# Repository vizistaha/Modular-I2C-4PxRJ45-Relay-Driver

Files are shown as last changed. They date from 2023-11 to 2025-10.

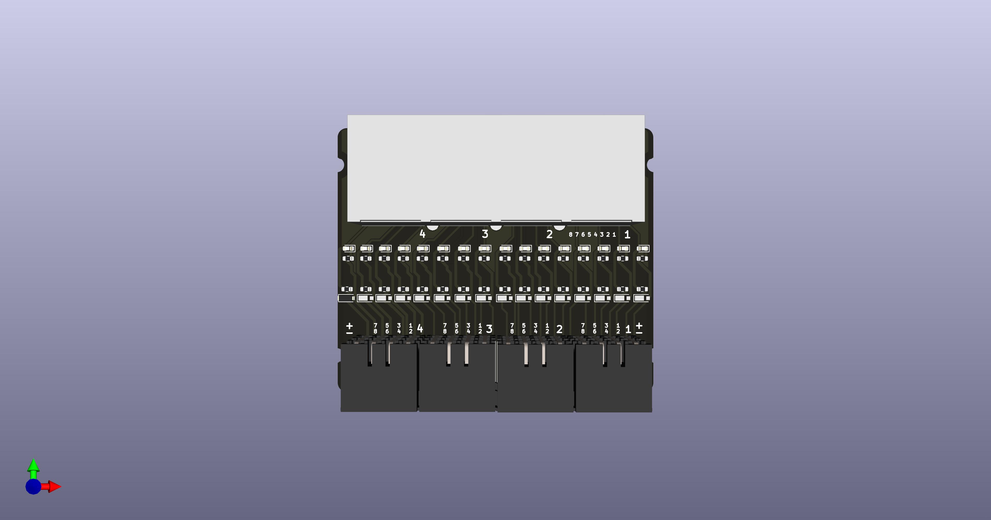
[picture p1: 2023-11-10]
RJ45toTerminal/RJ45-To-Terminal_3D.jpg

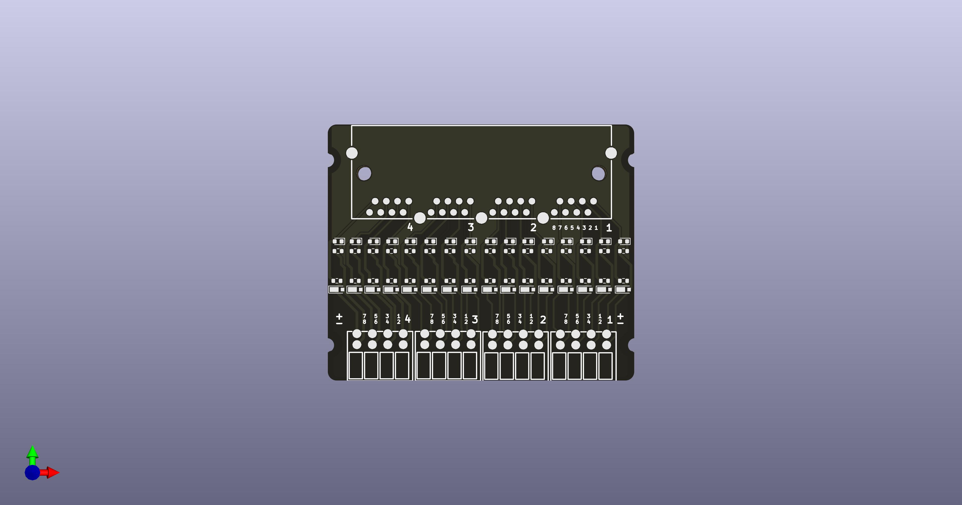
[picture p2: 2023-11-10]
RJ45toTerminal/RJ45-To-Terminal_Board.jpg

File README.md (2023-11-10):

# Modular-I2C-4PxRJ45-Relay-Driver
an oxrs compatible I2C-4PxRJ45-Relay-Driver board in a modular format. Inspired by 8-Channel Relay Driver Shield from Superhouse and Modular-I2CRJ45 from Austin's Creations.

rev 1 - non isolated version  
rev 2 - power circuit is fully isolated from mcu circuit by optocoupler  
rev 2_1 - output uses pluggable terminal instead of 4PxRJ45  
RJ45toTerminal - breakout board for rj45 to pluggable connector (check read me for pin mapping)

For more details about OXRS: https://oxrs.io/

Credits
-------
 * Austin's Creations <https://www.austinscreations.ca/>
 * Jonathan Oxer <https://www.superhouse.tv/>

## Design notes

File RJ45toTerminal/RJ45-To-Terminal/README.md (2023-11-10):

# RJ45 To Terminal Mapping

| Pin | Pair | Color | Terminal  | 
| --- |:---:| --- | --- |
| 1 | 1+ | Orange-White | 1 | 
| 2 | 1- | Orange | 2 |
| 3 | 2+ | Green-White  | 3 |
| 6 | 2- | Green | 4 |
| 5 | 3+ | Blue-White | 5 |
| 4 | 3- | Blue | 6 |
| 7 | 4+ | Brown-White  | 7 |
| 8 | 4- | Brown | 8 |

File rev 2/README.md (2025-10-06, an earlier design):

# RJ45 Pinout

| Pin | Pair | Color |
| --- |:---:| --- |
| 1 | 1+ | Orange-White |
| 2 | 1- | Orange |
| 3 | 2+ | Green-White  |
| 6 | 2- | Green |
| 5 | 3+ | Blue-White |
| 4 | 3- | Blue |
| 7 | 4+ | Brown-White  |
| 8 | 4- | Brown |

VIN Jumper Connection

| VIN | JP1 | JP2 | JP3 |
| --- |:--- | --- | --- |
| 24V | VIN | 5V | ON |
| 12V | VIN | 5V | ON |
| 5V | VIN | VIN | OFF |

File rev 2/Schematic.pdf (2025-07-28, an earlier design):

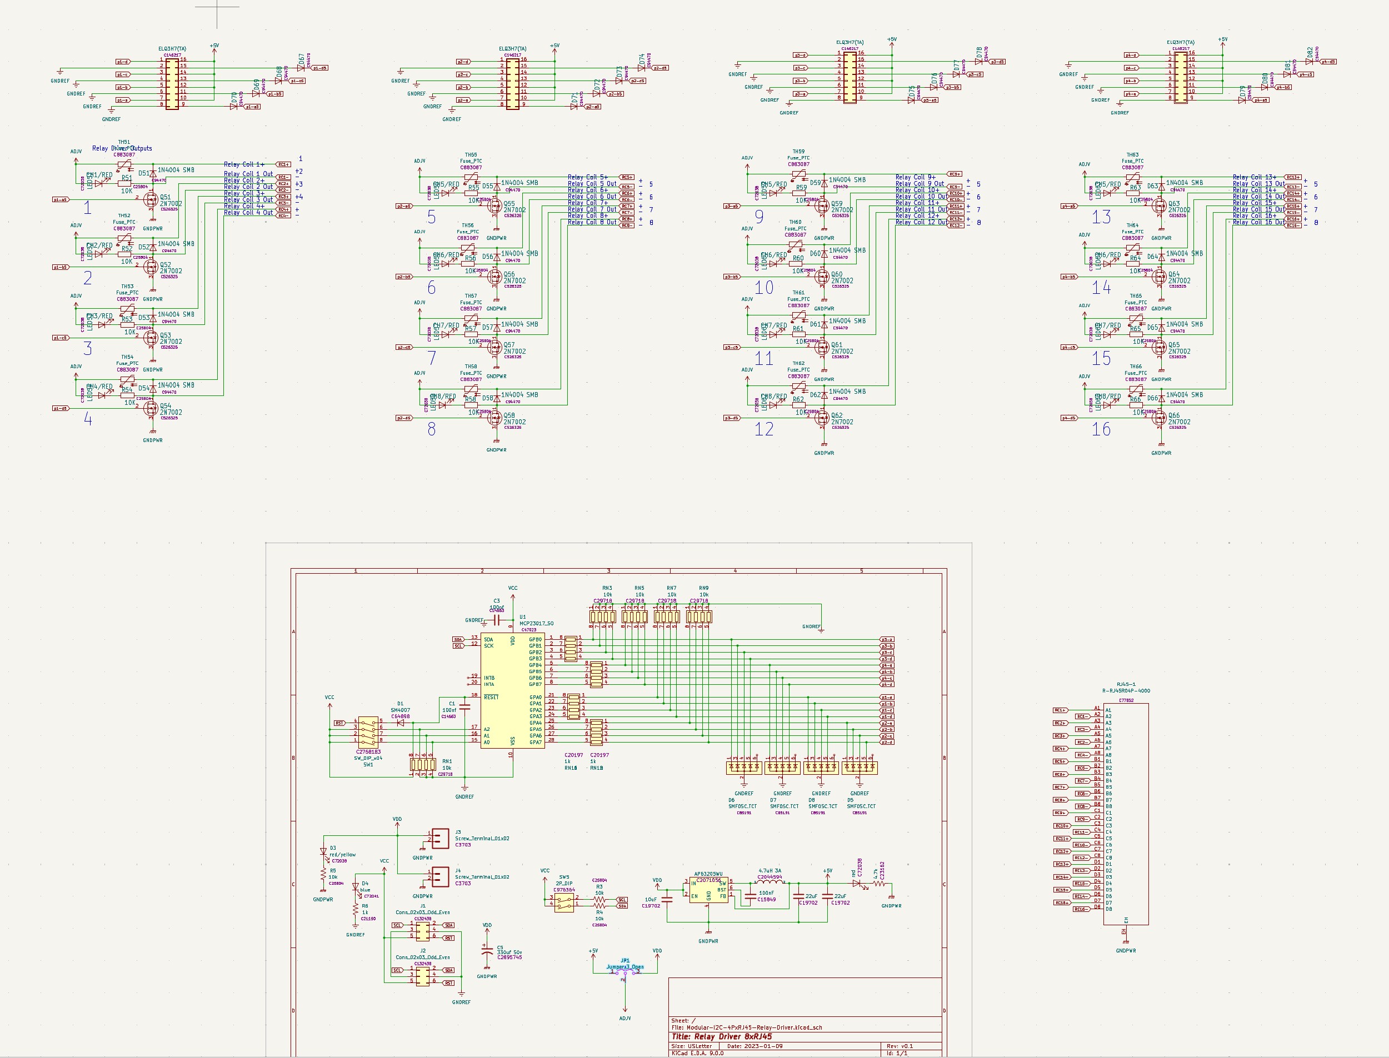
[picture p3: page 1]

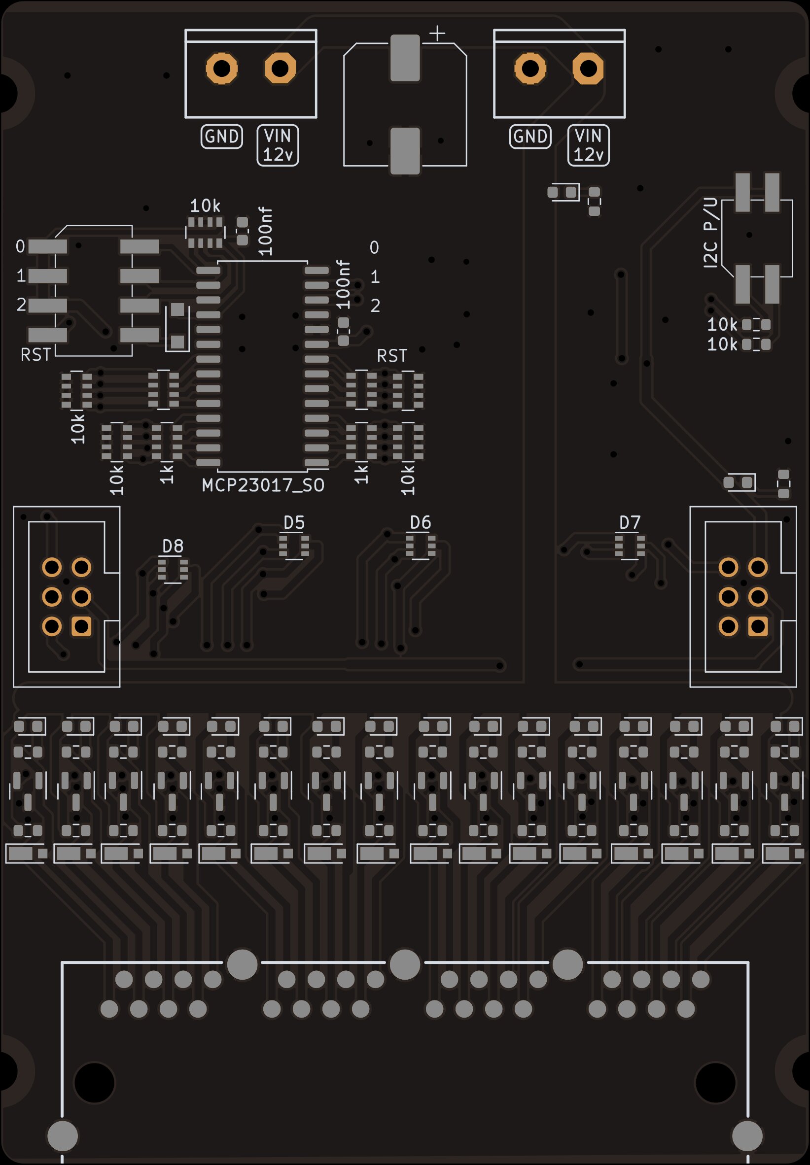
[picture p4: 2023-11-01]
release_files/Renders/Modular-I2C-4PxRJ45-Relay-Driver-green-top.jpg

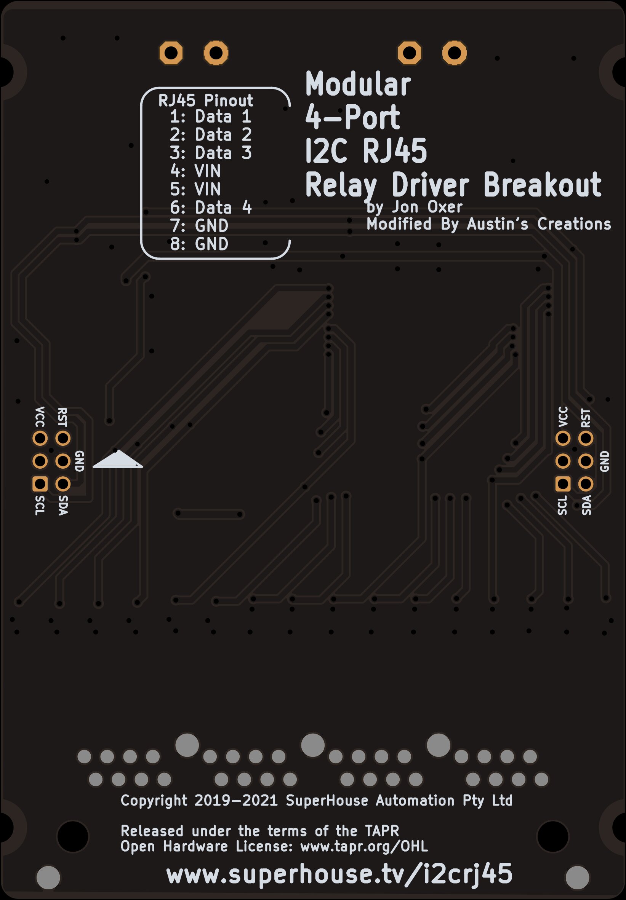
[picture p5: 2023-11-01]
release_files/Renders/Modular-I2C-4PxRJ45-Relay-Driver-green-bottom.jpg

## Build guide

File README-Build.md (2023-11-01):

# KiBot CI/CD template repository for KiCad 6

This repository provides a ready-to-go CI/CD workflow for KiCad 6 with GitHub actions. Using KiCad5? [See my other repo](https://github.com/neilenns/KiBot-CICD-Template).

## Features of this repository template

1. Integration with GitHub releases to automatically produce documentation and
   fabrication files on every GitHub release, including automatic date and version
   stamping of schematics and PCBs.
2. KiBot preflighting on every pull request (ERC/DRC checks disabled by default).
3. External GitHub repo for custom components, including using 3D models from that repo during output generation.
4. VSCode dev container and default build task for easy local testing of KiBot scripts.

## Creating your GitHub repo and KiCad project

To create a KiCad project using this GitHub template:

1. Hit the _Use this template_ button then follow the steps from GitHub to create a copy of the repo. **The repository name must exactly match the name of the KiCad project.
   Do not use spaces in either the repository or the project name.**
2. Clone the new repo locally.
3. Go to _File_ > _New_ > _Project..._ in KiCad.
4. Name the project the exact same name as the GitHub repository name.
5. Uncheck the _Create a new directory for this project_ option. **This is very important!**
6. Save the project into the top level of the folder for the GitHub repository.

Do not use spaces in the GitHub repository or KiCad project name. Use underscores or hyphens instead, for example `TBM930_De-Ice_-_Panel` or `Collins-FMS-3000`.

If you've done all the steps correctly the folder structure will look similar like this:



Notice that the folder name (which is also the GitHub repo name) and project name are exactly the same and there are no spaces.

## Setting up date and version number replacement

The GitHub automation can automatically set the date and version number in the generated schematic and PCBs. Before using this make sure
to set the timezone to your local timezone in the `.github\workflows\includes\shared-settings.yml` file.

The verison number for the release will be inserted anywhere `${VERSION}` appears in the schematic or PCB design. Typical places to use
this are in the `Revision` field of the schematic and board setup, and in silkscreen or copper layer text on the PCB.

The date for the release will be inserted anywhere `${DATE}` appears in the schematic or PCB design. Typical places to use
this are in the `Date` field of the schematic and board setup, and in silkscreen on the PCB.

## JLCPCB BOM generation

This repo will automatically generate the necessary files for JLCPCB's SMT assembly service. To make it work add the LCSC part number to the
`MPN - JLCPCB` field on each symbol. Chances are after generation at least one component will be rotated
incorrectly. Blame JLCPCB, it sucks. To correct the rotation edit the `.kibot/includes/JLCPCB-2layer.kibot.yaml` file, modifying the `rotations`
section as necessary.

## Using an external GitHub repo for custom components

If you use a second GitHub repo to store your custom components the custom symbols and footprints will work fine with this
automation without any extra effort. If you have custom 3D models you'll need to uncomment a few lines and
point to your custom repo in one of the script files.

1. In `.github\workflows\documentation-only.yml` uncomment the `Checkout component` step and update the `repository` value to reference your
component repository.
2. In `.github\workflows\release.yml` uncomment the `Checkout component` step and update the `repository` value to reference your
component repository.
3. In `.kibot\includes\shared-settings.yaml` uncomment the text variable `KICAD6_USER_COMPONENTS_DIR` and set its value to the name of your
custom component repository folder. **This is case sensitive!**.
4. In KiCad use `${KICAD6_USER_COMPONENTS_DIR}` to reference the path to your custom components when assigning 3D models to footprints.
It's a good idea to use the same variable to reference the symbol and footprint library as well.

An example custom component GitHub structure is available at https://github.com/neilenns/KiCad6-Components.

## Documentation generated

The following documents are generated on every release build:

- Schematic - PDF
- BOM - Interactive HTML
- PCB front copper and explanatory drawings layers - PDF
- PCB back copper and explanatory drawings layers - PDF
- 3D render - STEP
- PCB front - JPEG
- PCB back - JPEG

These documents can also be generated by manually running the `KiBot - Generate documentation` action on GitHub.

## Fabrication files generated

The following fabrication files are generated on every release build:

- JLCPCB gerbers and drill files, with BOM and placement files for SMT service
- PCBWay gerbers and drill files

For JLCPCB BOM generation the symbols should be associated to the LCSC part number via a
`MPN - JLCPCB` custom symbol field.

The fabrication files can also be generated by manually running the `KiBot - Release` action on GitHub.

## Running builds locally

This repository template includes the files necessary to run in a VSCode dev container,
which dramatically reduces the effort required to use KiBot on Windows machines.

Never used VSCode remote containers before on Windows? Here's how to get set up:

1. From a PowerShell install WSL2 with this command: `wsl --install`
2. Install [Visual Studio Code](https://code.visualstudio.com/Download) and Docker Desktop(https://www.docker.com/products/docker-desktop)
3. Install the [Remote Containers](https://marketplace.visualstudio.com/items?itemName=ms-vscode-remote.remote-containers) extension for VSCode

When installing Docker Desktop you may be told you have to enable virtualization in your computer's BIOS. Setting that up
is outside the scope of this readme but isn't hard. Just do a web search for your motherboard for how to enter the BIOS
and what the exact name of the setting is, then turn it on.

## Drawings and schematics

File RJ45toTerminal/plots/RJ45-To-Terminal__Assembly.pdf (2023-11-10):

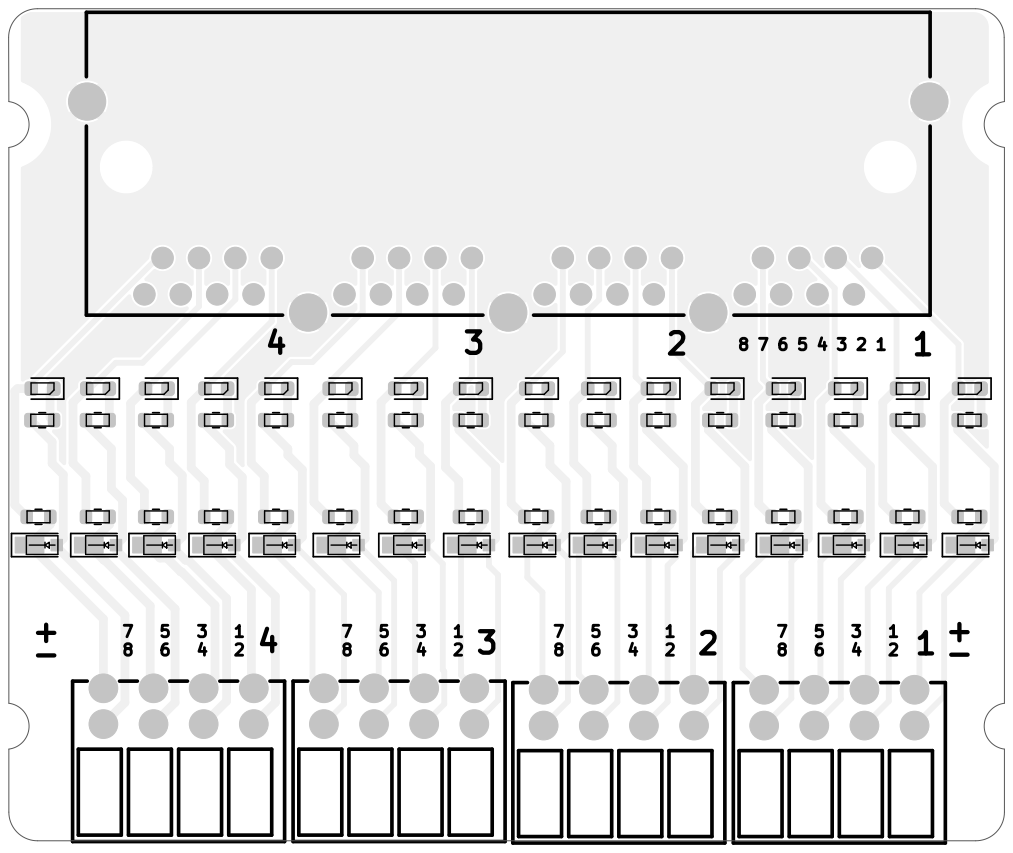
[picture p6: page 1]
D Date: KiCad E.D.A. kicad (6.0.9) Size: A4; Rev: 2

File: RJ45-To-Terminal.kicad_pcb Sheet: Black-And-White-TOP
Id: 1/1 Title: Modular 4-Port I2CRJ45 Relay Driver Breakout

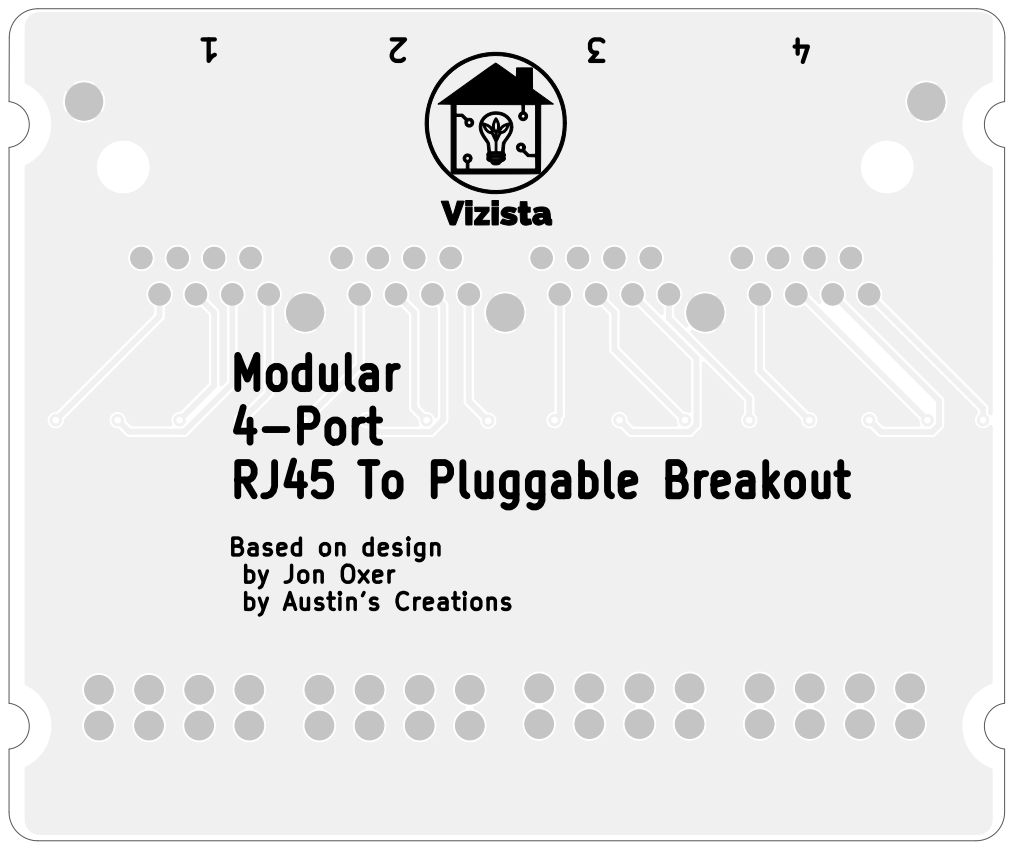
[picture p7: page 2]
D Date: KiCad E.D.A. kicad (6.0.9) Size: A4; Rev: 2

4-Port
RJ45 To Pluggable Breakout Based on design

by Jon Oxer
by Austin's Creations

File: RJ45-To-Terminal.kicad_pcb Sheet: Black-And-White-BOT
Id: 1/1 Title: Modular 4-Port I2CRJ45 Relay Driver Breakout

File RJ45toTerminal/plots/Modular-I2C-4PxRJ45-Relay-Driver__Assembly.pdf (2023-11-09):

# 1 GND

# RST +

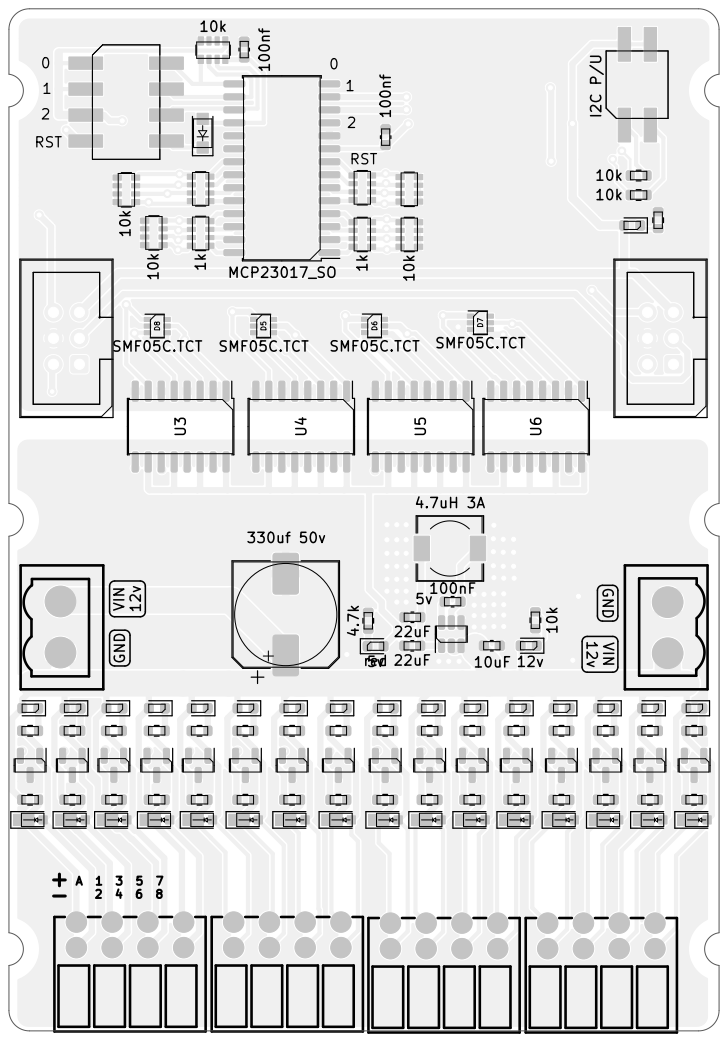
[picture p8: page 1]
RST; GND ¹⁰k; I2C P/U 12v VIN VIN 12v; 12v ¹⁰k; 5v ¹⁰⁰nf10k; 10k MCP23017_SO; 100nF ¹⁰⁰nf 4.7k; D Date: KiCad E.D.A. kicad (6.0.9) Size: A4; Rev: 2; File: Modular-I2C-4PxRJ45-Relay-Driver.kicad_pcb Sheet: Black-And-White-TOP U⁵ SMF05C.TCT D⁸; SMF05C.TCT D⁷ red SMF05C.TCT D⁶ U³; U⁶ SMF05C.TCT D⁵

Id: 1/1 Title: Modular 4-Port I2CRJ45 Relay Driver Breakout

Relay Driver Breakout | VCC | RSTRST

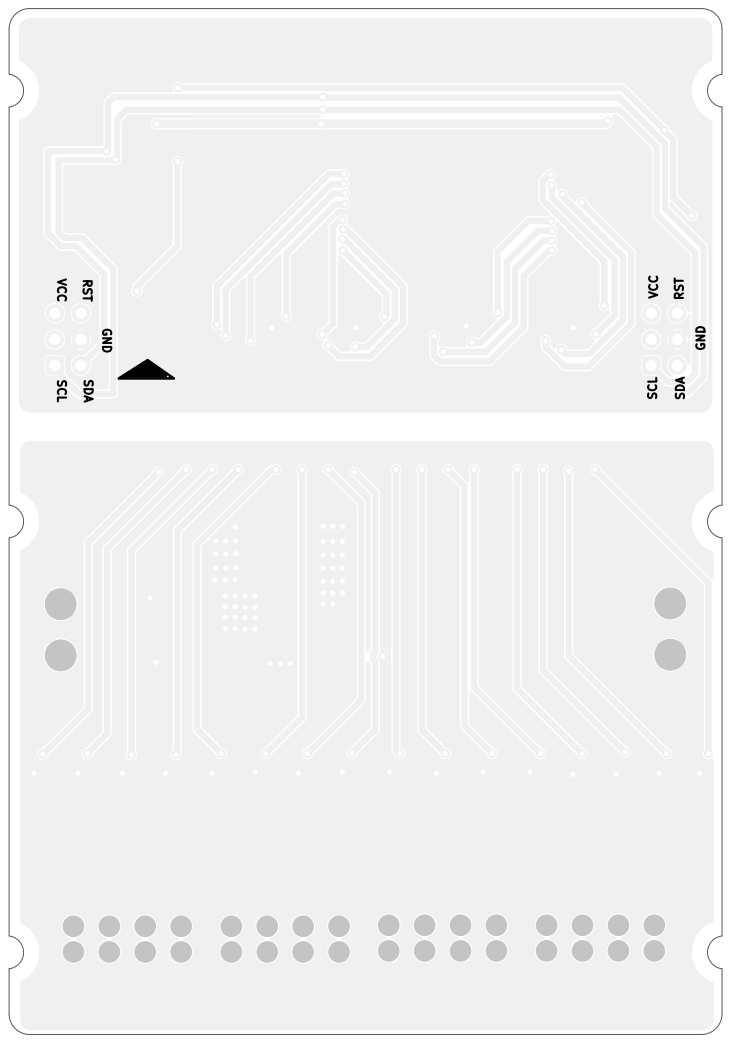
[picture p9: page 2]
8: GND; GND SDA; modified by Mattar; SCLSCL; SDA; GND VCC 1; D Date: KiCad E.D.A. kicad (6.0.9) Size: A4; Rev: 2

File: Modular-I2C-4PxRJ45-Relay-Driver.kicad_pcb Sheet: Black-And-White-BOT
Id: 1/1 Title: Modular 4-Port I2CRJ45 Relay Driver Breakout

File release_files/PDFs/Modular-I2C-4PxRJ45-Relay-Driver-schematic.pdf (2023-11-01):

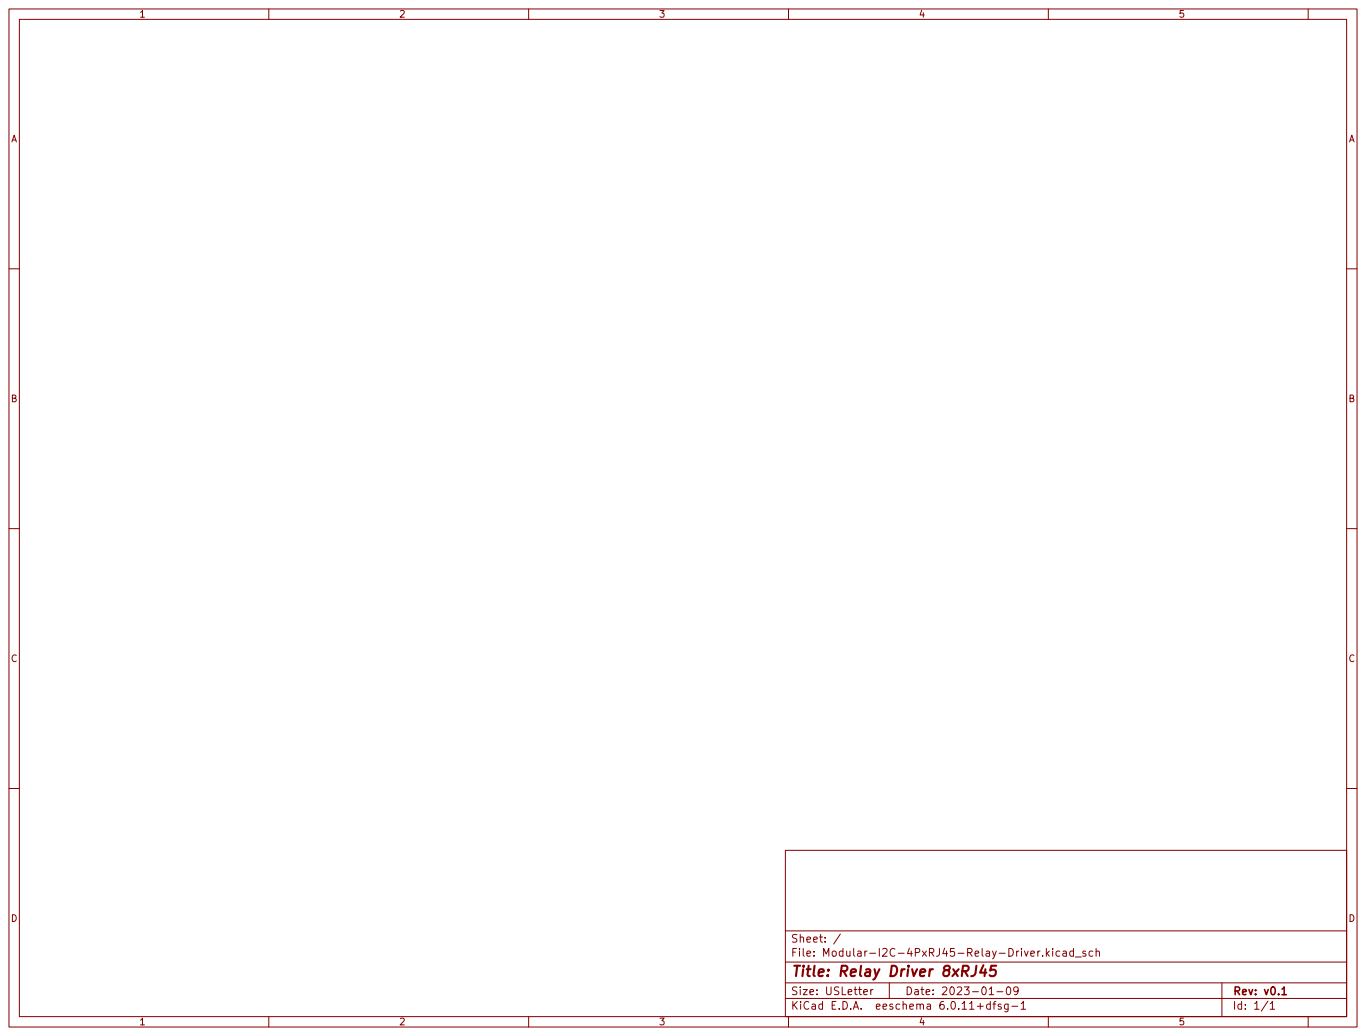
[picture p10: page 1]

File: Modular-I2C-4PxRJ45-Relay-Driver.kicad_sch Sheet: /
Id: 1/1 Title: Relay Driver 8xRJ45

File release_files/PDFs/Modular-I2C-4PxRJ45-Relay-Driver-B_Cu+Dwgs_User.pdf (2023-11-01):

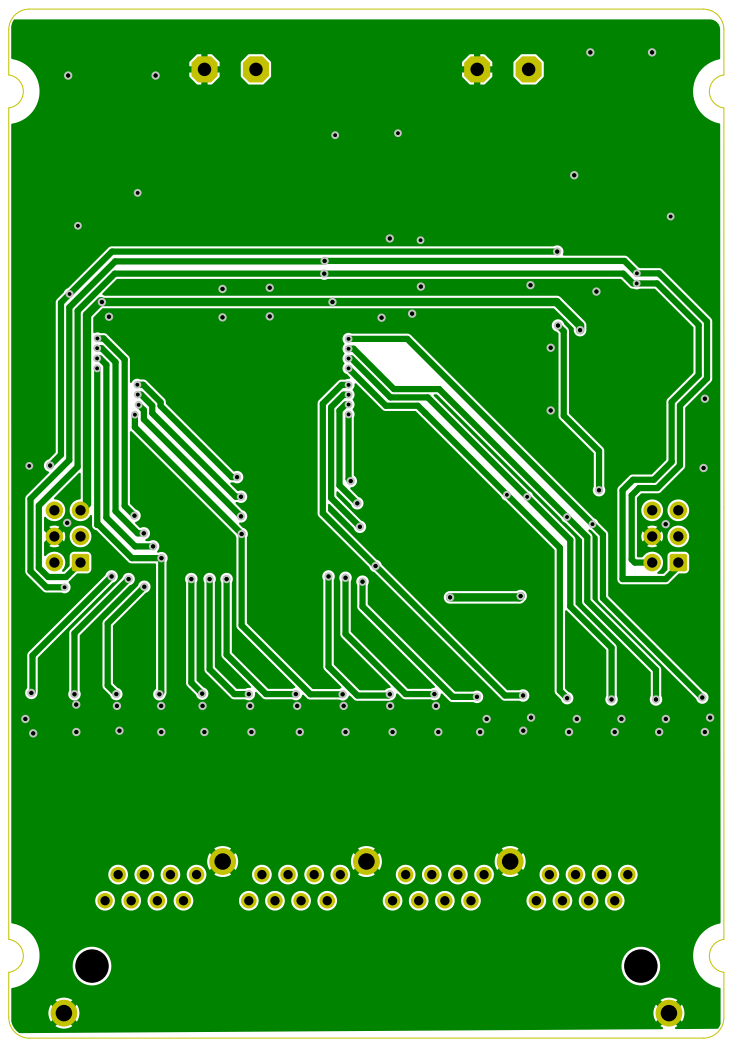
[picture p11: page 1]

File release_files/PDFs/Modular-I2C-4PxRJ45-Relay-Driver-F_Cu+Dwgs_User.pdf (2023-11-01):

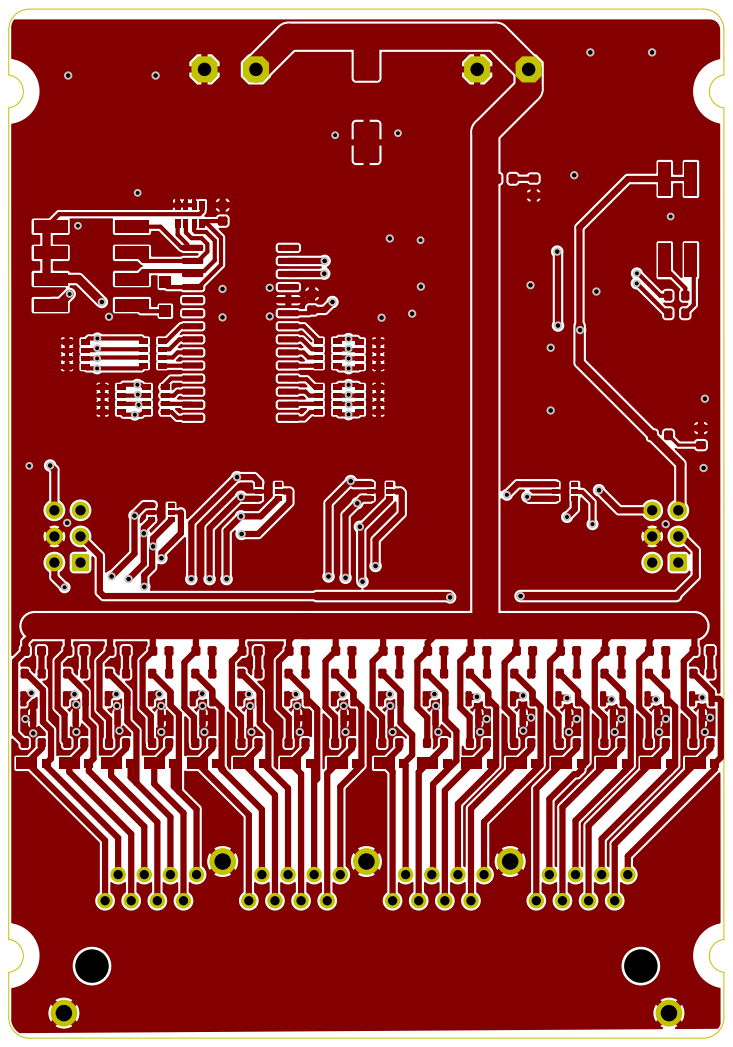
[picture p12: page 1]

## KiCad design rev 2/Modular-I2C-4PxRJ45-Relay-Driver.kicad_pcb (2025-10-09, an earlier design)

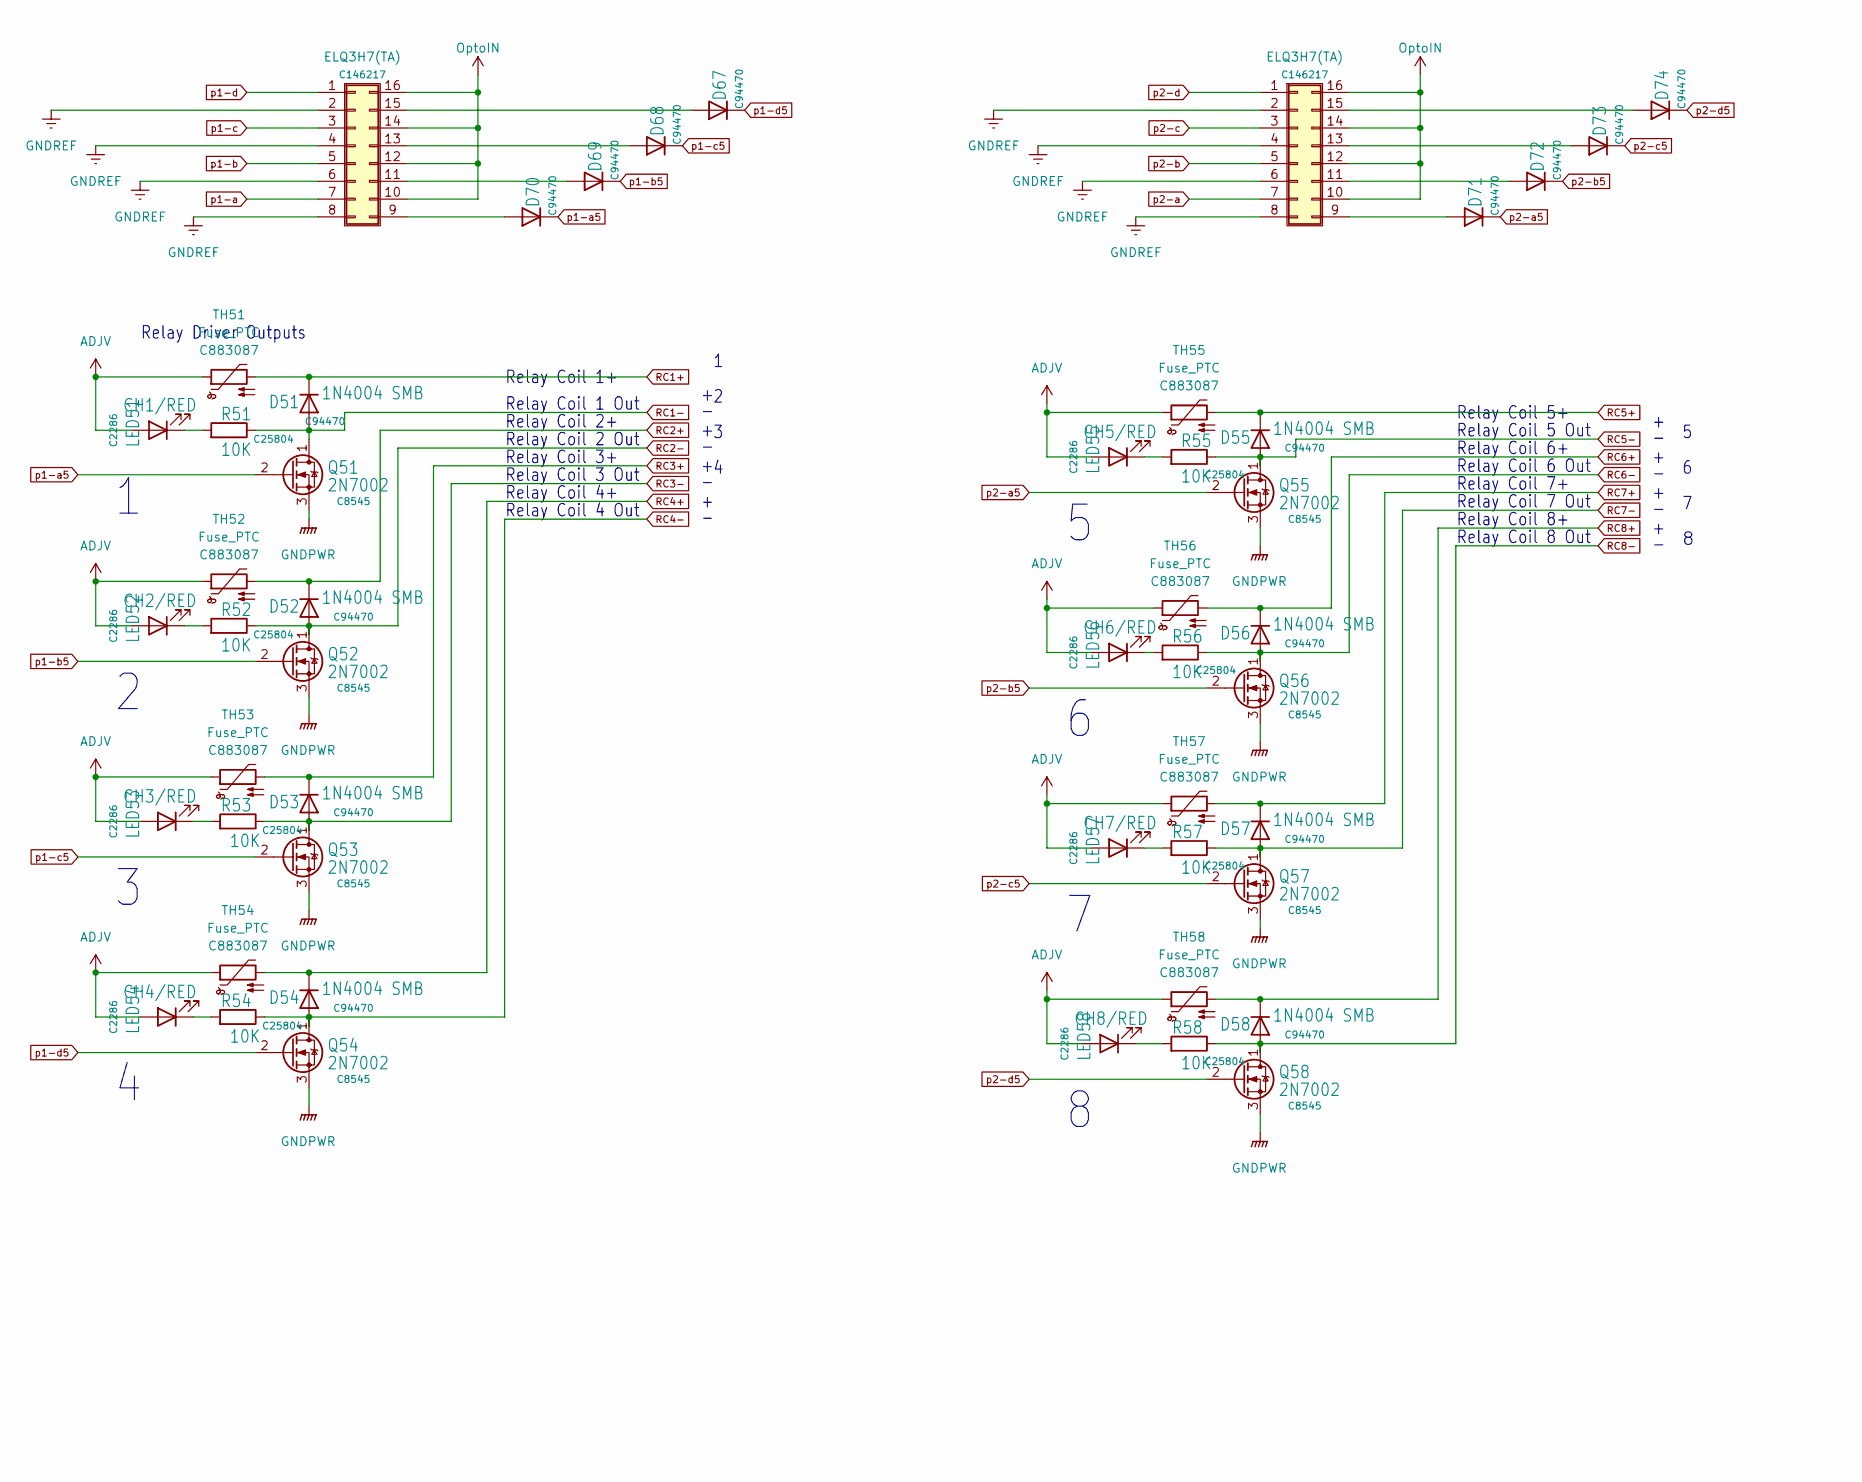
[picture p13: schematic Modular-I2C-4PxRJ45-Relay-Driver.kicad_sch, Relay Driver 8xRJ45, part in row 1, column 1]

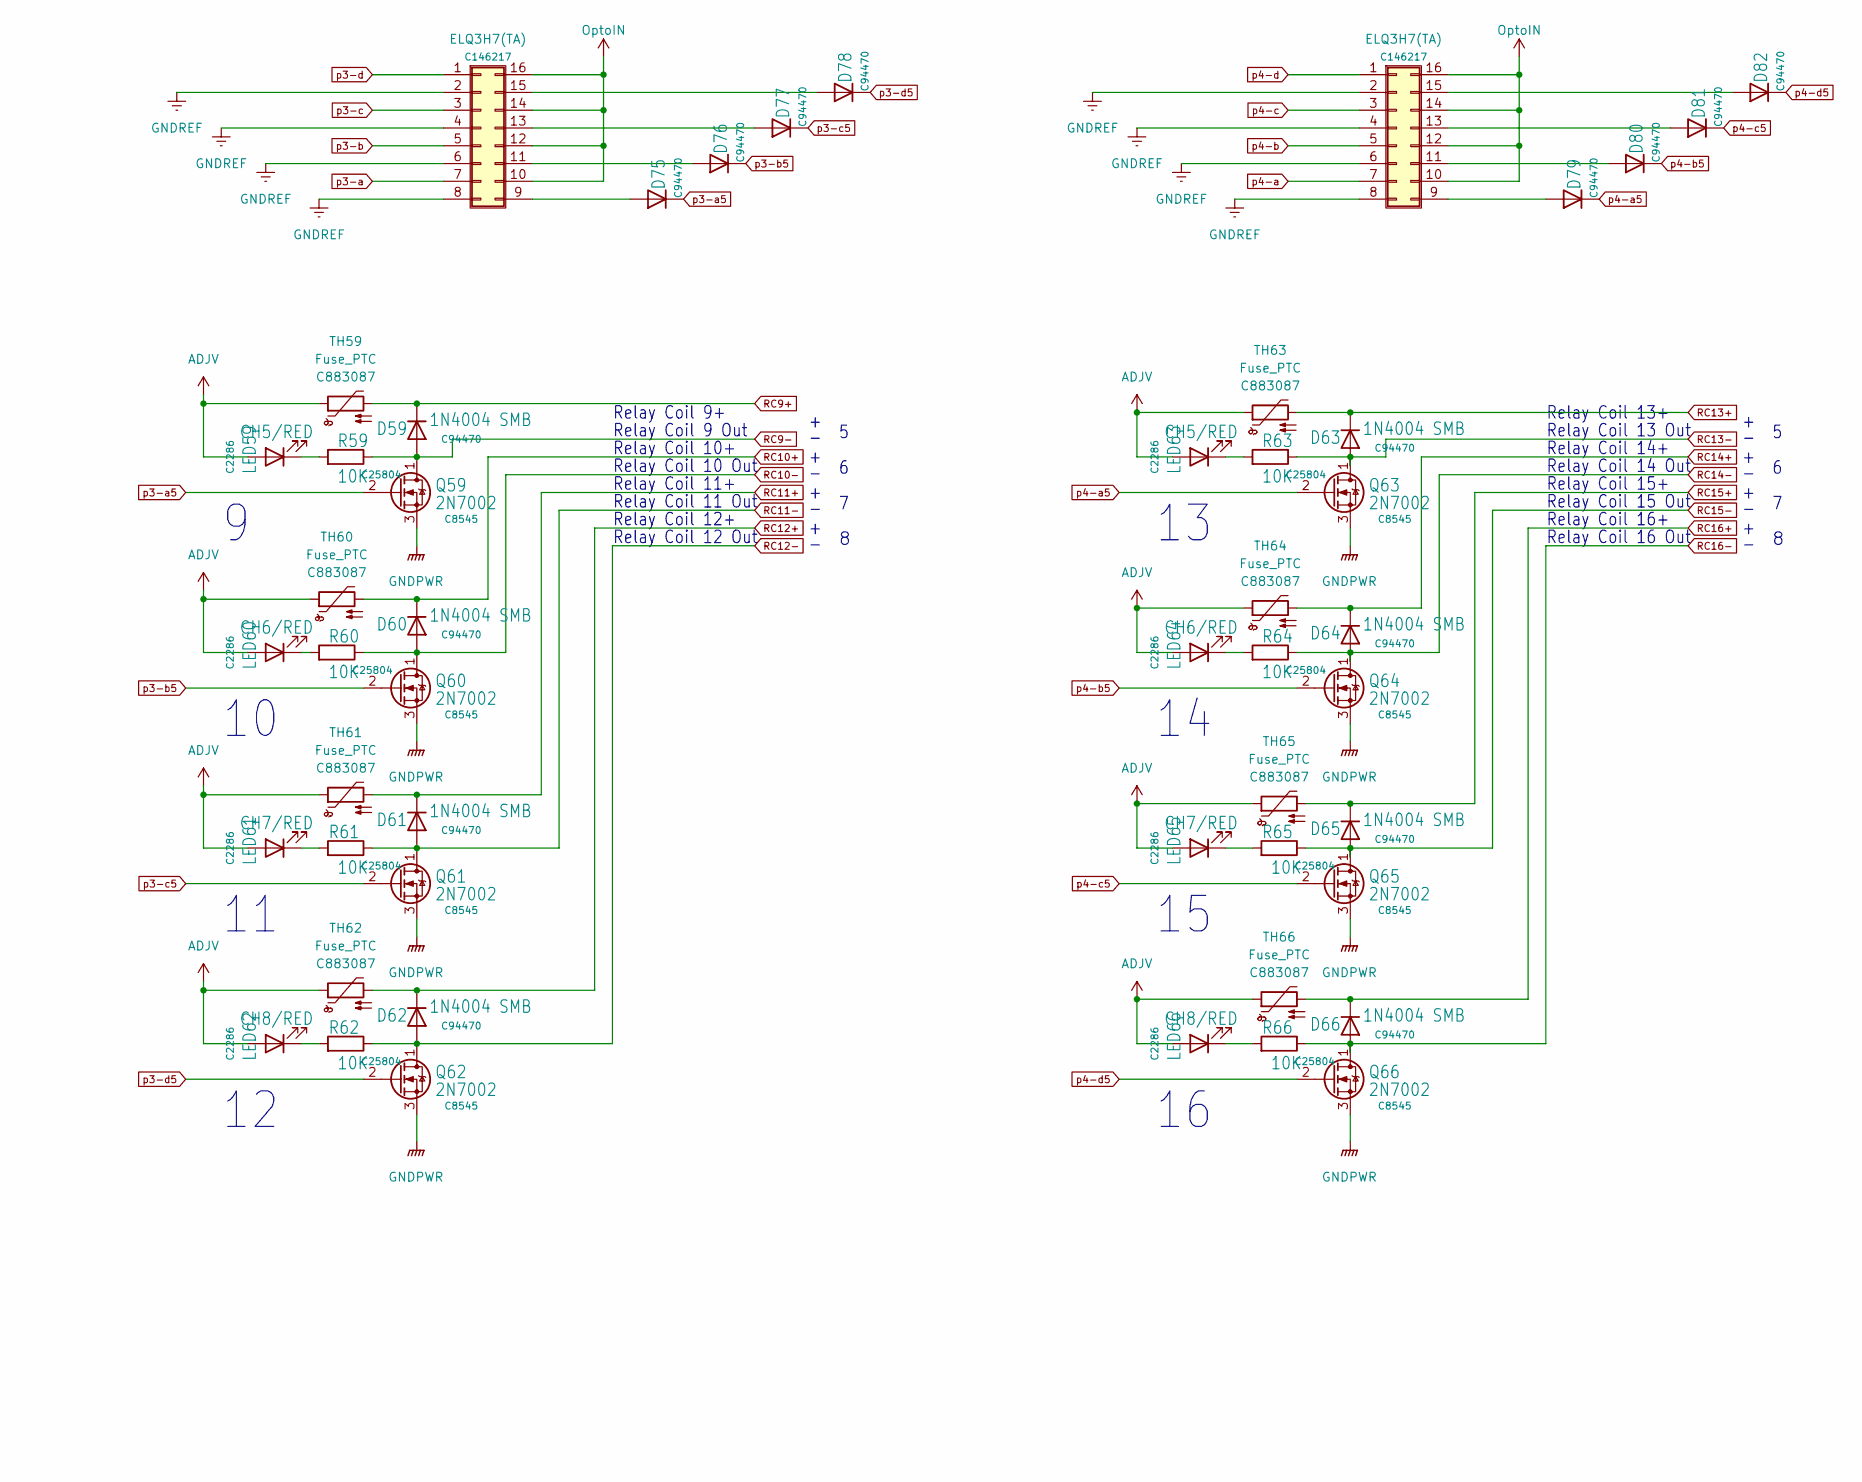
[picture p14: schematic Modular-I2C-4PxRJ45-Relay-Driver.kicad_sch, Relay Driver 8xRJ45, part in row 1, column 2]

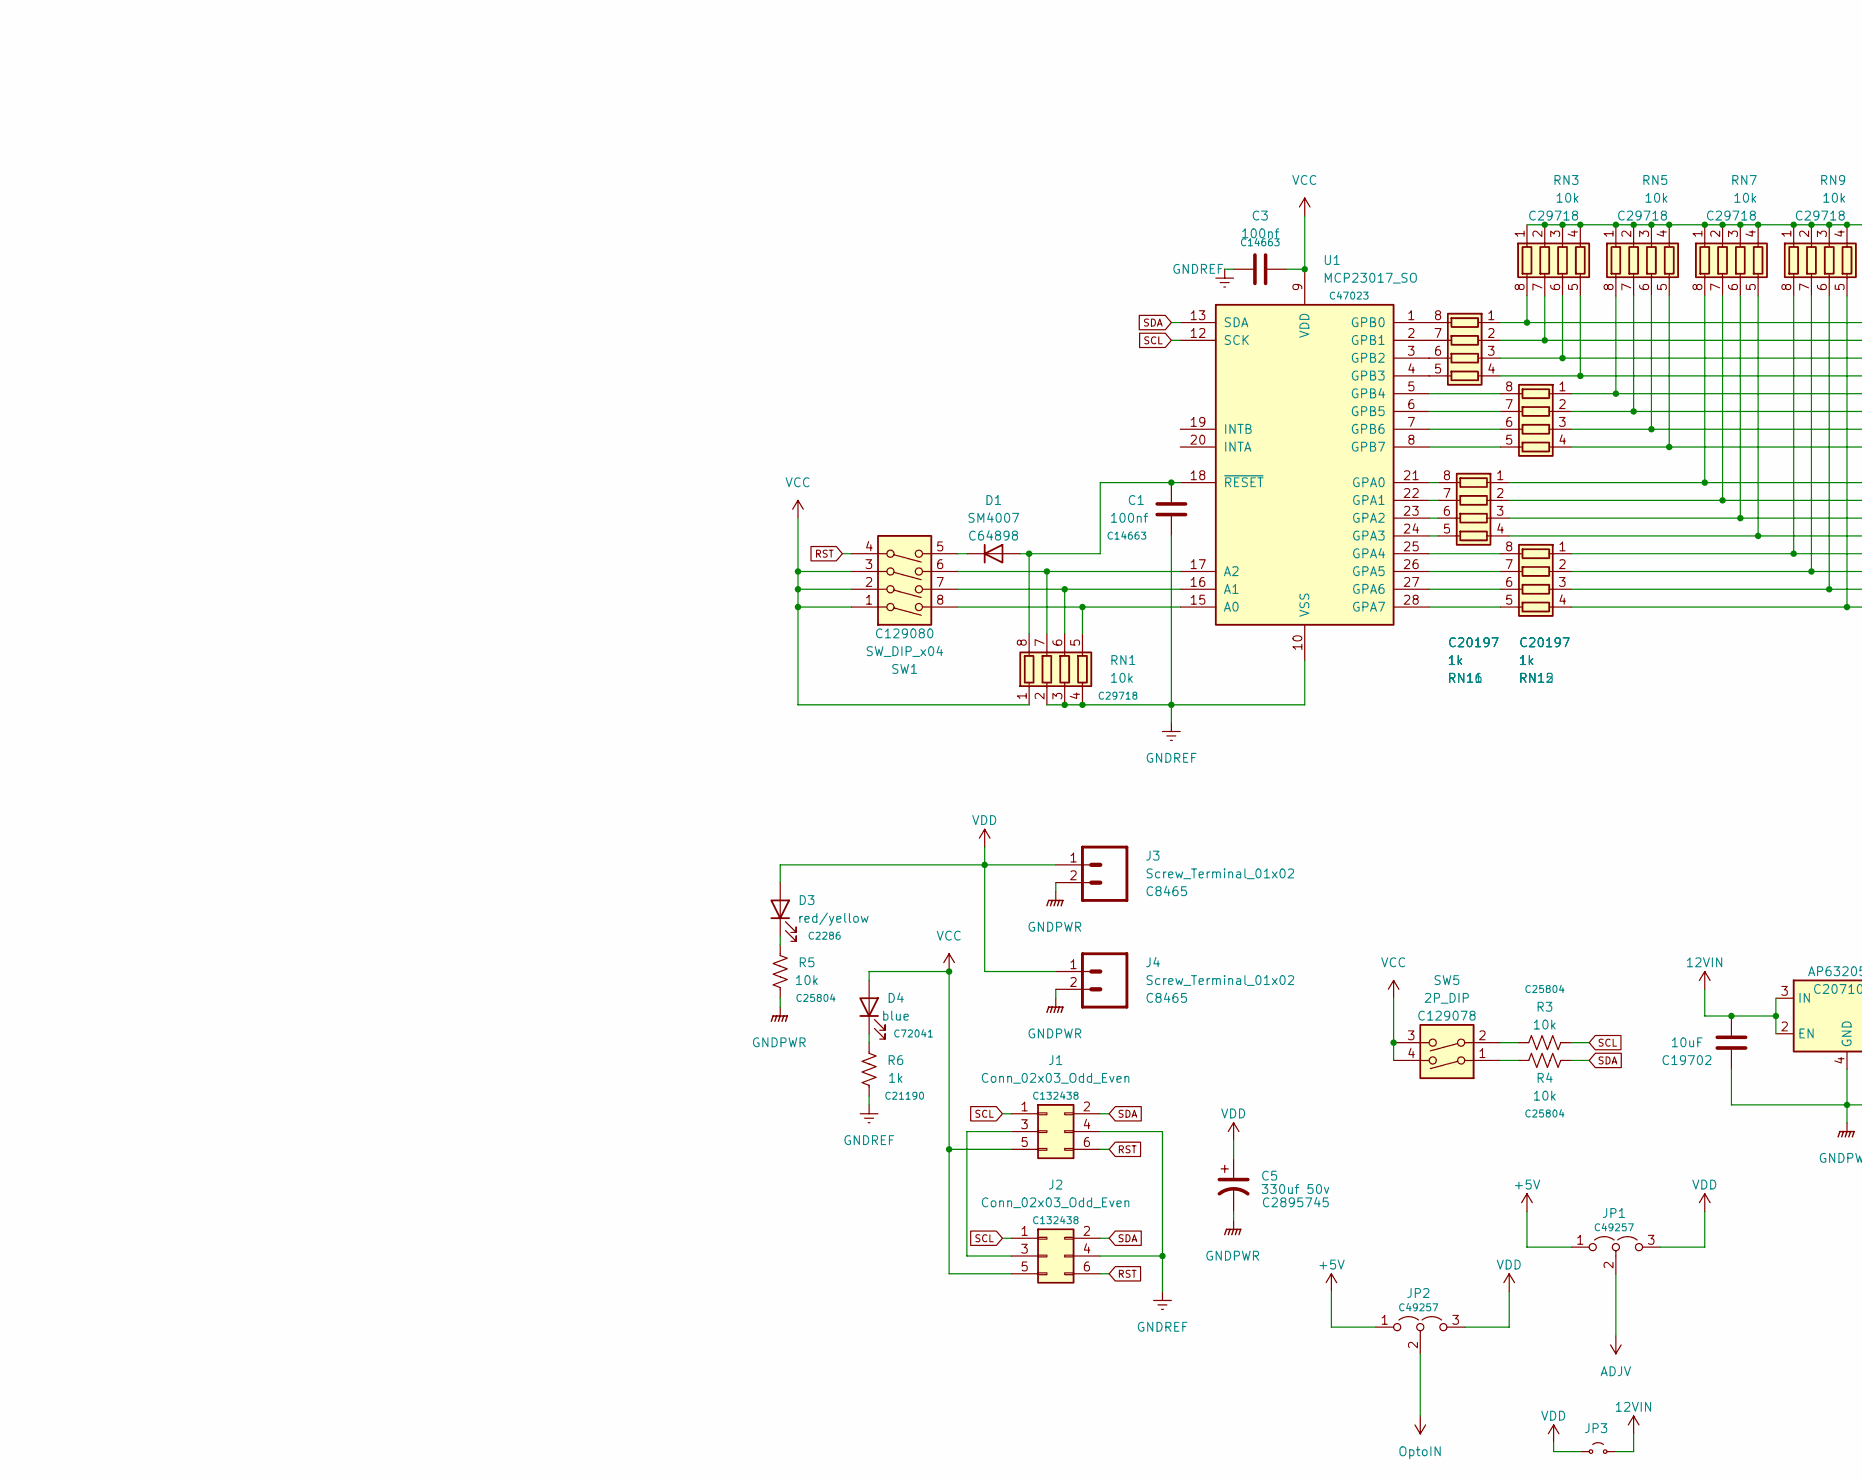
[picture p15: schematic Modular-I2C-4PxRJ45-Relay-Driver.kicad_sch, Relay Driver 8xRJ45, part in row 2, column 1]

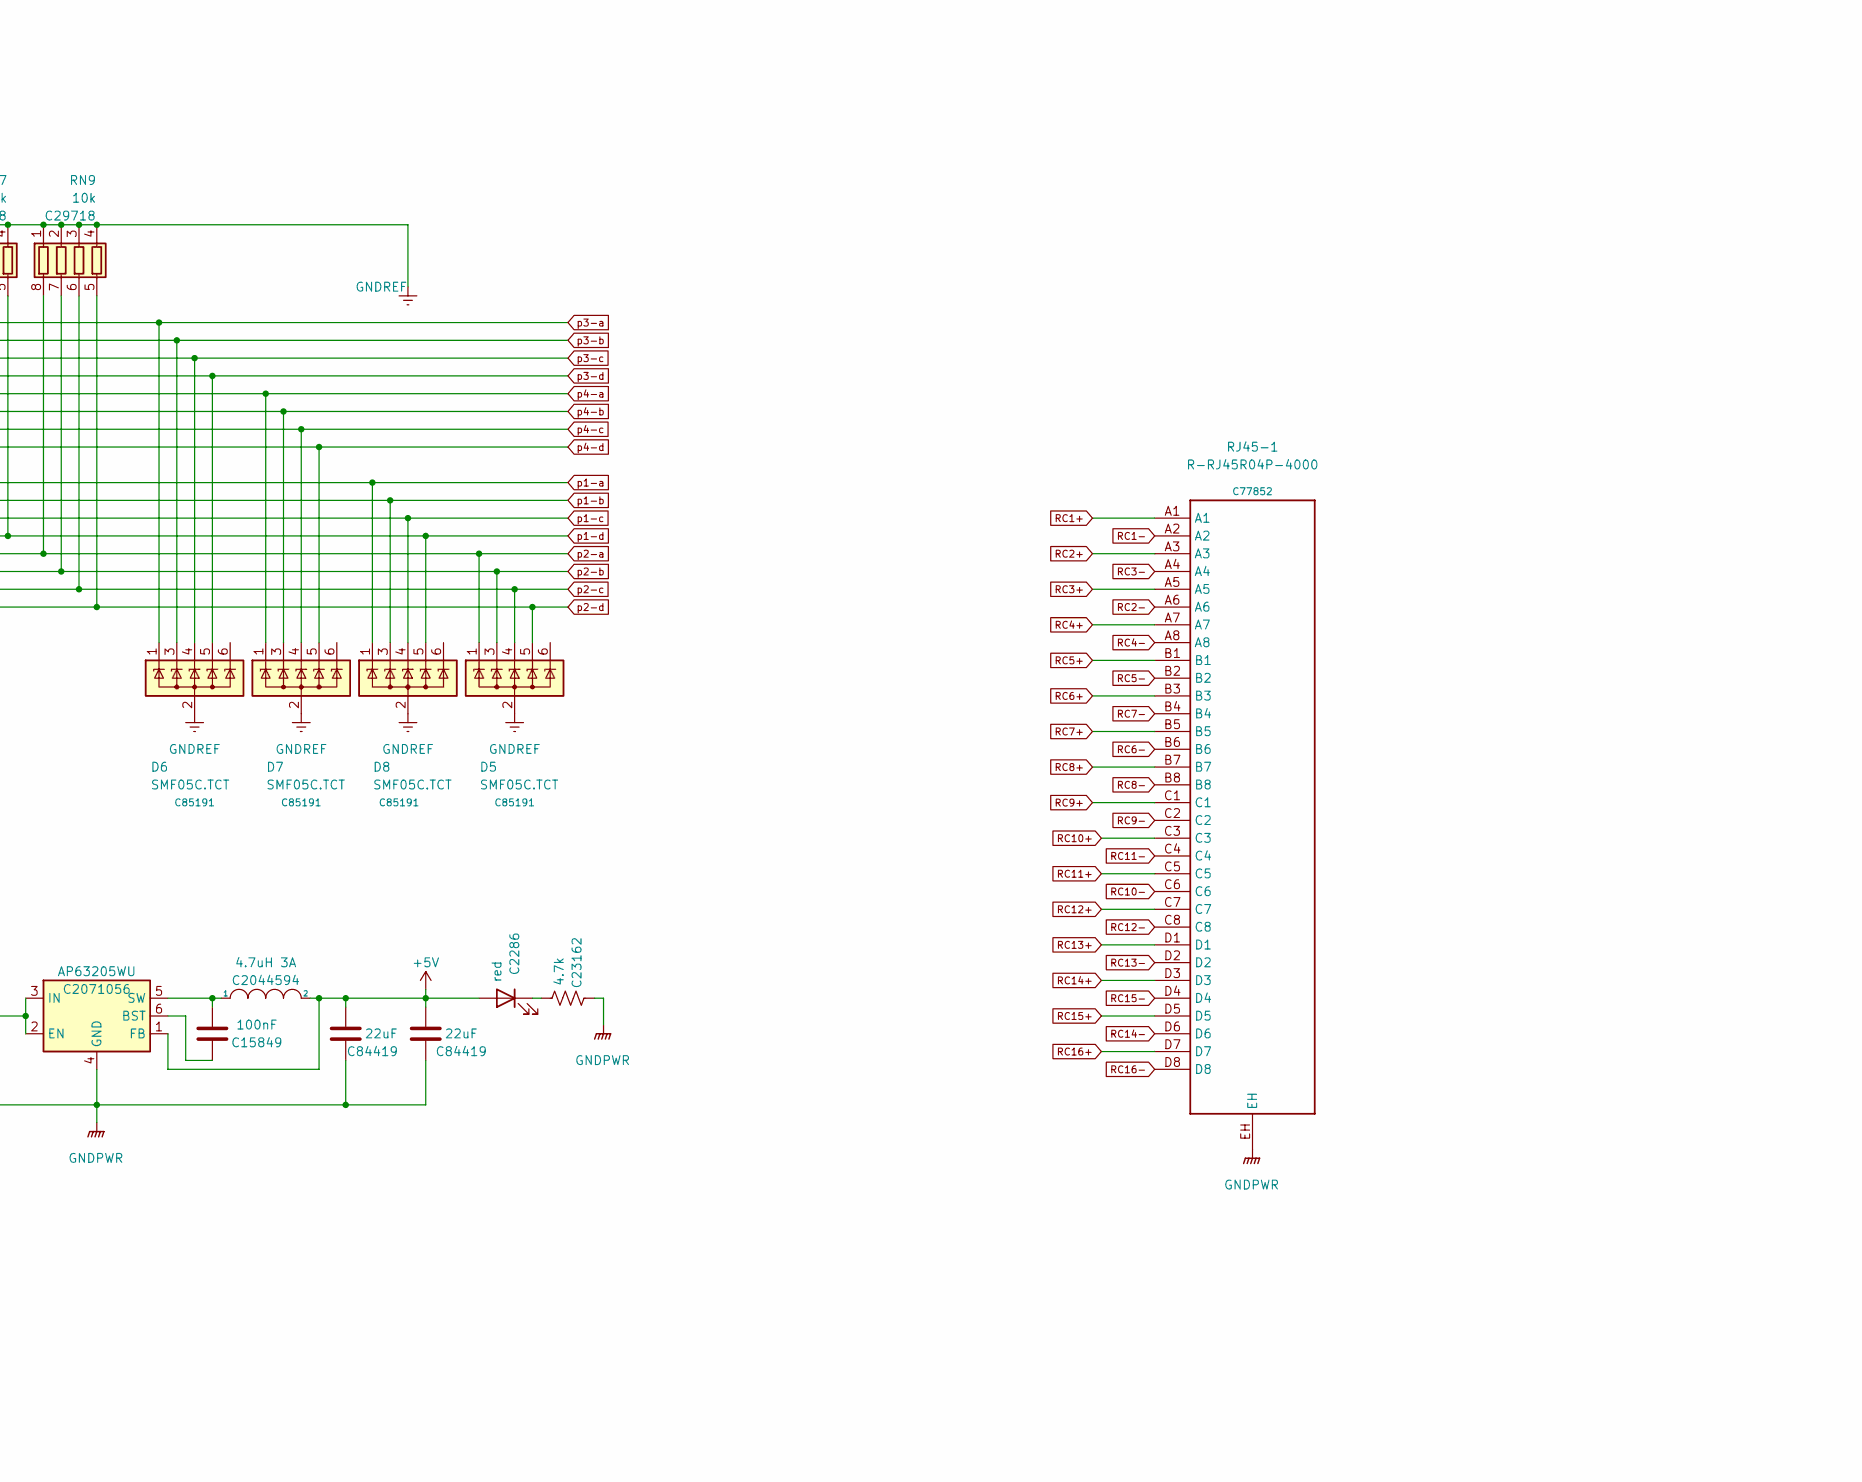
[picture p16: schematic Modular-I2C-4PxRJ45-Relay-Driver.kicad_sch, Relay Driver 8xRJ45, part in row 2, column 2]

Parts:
C1, C3: 100nf; C_0603_1608Metric; LCSC C14663
C5: 330uf 50v; CP_Elec_10x10; LCSC C2895745
C6: 100nF; C_0603_1608Metric; LCSC C15849
C7, C8: 22uF; C_0603_1608Metric; LCSC C84419
C9: 10uF; C_0603_1608Metric; LCSC C19702
D1: SM4007; D_SOD-123F; LCSC C64898
D2: red; LED_0603_1608Metric; LCSC C2286
D3: red/yellow; LED_0603_1608Metric; LCSC C2286
D4: blue; LED_0603_1608Metric; LCSC C72041
D5, D6, D7, D8: SMF05C.TCT; SOT-363_SC-70-6; LCSC C85191
D51: 1N4004 SMB; D_MicroSMP; LCSC_old C727080
D52, D53, D54, D55, D56, D57, D58, D59, D60, D61, D62, D63, D64, D65, D66: 1N4004 SMB; D_MicroSMP; LCSC C94470
D67, D68, D69, D70, D71, D72, D73, D74, D75, D76, D77, D78, D79, D80, D81, D82: 1N4004 SMB; LCSC-C94470-MICROSMP_L2.2-W1.3-LS2.5-RD; LCSC_old C727080
J1, J2: Conn_02x03_Odd_Even; IDC-Header_2x03_P2.54mm_Vertical; LCSC C132438
J3, J4: Screw_Terminal_01x02; LCSC-C8465-CONN-TH_2P-P5.00_WJ500V-5.08-2P; LCSC C8465
JP1, JP2: Jumper_3_Open; PinHeader_1x03_P2.54mm_Vertical; LCSC C49257
JP3: Jumper_2_Small_Open; PinHeader_1x02_P2.54mm_Vertical; LCSC C492401
L1: 4.7uH 3A; L_6.3x6.3_H3; LCSC C2044594
LED51: CH1/RED; LED_0603_1608Metric; LCSC C2286
LED52: CH2/RED; LED_0603_1608Metric; LCSC C2286
LED53: CH3/RED; LED_0603_1608Metric; LCSC C2286
LED54: CH4/RED; LED_0603_1608Metric; LCSC C2286
LED55, LED59, LED63: CH5/RED; LED_0603_1608Metric; LCSC C2286
LED56, LED60, LED64: CH6/RED; LED_0603_1608Metric; LCSC C2286
LED57, LED61, LED65: CH7/RED; LED_0603_1608Metric; LCSC C2286
LED58, LED62, LED66: CH8/RED; LED_0603_1608Metric; LCSC C2286
Q51, Q52, Q53, Q54, Q55, Q56, Q57, Q58, Q59, Q60, Q61, Q62, Q63, Q64, Q65, Q66: 2N7002; SOT-23; LCSC C8545
R1: 4.7k; R_0603_1608Metric; LCSC C23162
R3, R4, R5: 10k; R_0603_1608Metric; LCSC C25804
R6: 1k; R_0603_1608Metric; LCSC C21190
R51, R52, R53, R54, R55, R56, R57, R58, R59, R60, R61, R62, R63, R64, R65, R66: 10K; R_0603_1608Metric; LCSC C25804
RJ45-1: R-RJ45R04P-4000; CONN-TH_DS1129-02-S80BP; LCSC C77852
RN1, RN3, RN5, RN7, RN9: 10k; R_Array_Convex_4x0603; LCSC C29718
RN11, RN12, RN15, RN16: 1k; R_Array_Convex_4x0603; LCSC C20197
SW1: SW_DIP_x04; 4P_DIP; LCSC C129080
SW5: 2P_DIP; LCSC C129078
TH51, TH52, TH53, TH54, TH55, TH56, TH57, TH58, TH59, TH60, TH61, TH62, TH63, TH64, TH65, TH66: Fuse_PTC; R_0603_1608Metric; LCSC C883087
U1: MCP23017_SO; SOIC-28W_7.5x17.9mm_P1.27mm; LCSC C47023
U2: AP63205WU; TSOT-23-6; LCSC C2071056
U3, U4, U5, U6: ELQ3H7(TA); SO-16_5.3x10.2mm_P1.27mm; LCSC C146217

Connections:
12VIN: C9.2, JP3.2 (B), U2.2 (EN), U2.3 (IN)
+5V: C7.2, C8.2, D2.2 (A), JP1.1 (A), JP2.1 (A), L1.2, U2.1 (FB)
ADJV: JP1.2 (C), LED51.2 (A), LED52.2 (A), LED53.2 (A), LED54.2 (A), LED55.2 (A), LED56.2 (A), LED57.2 (A), LED58.2 (A), LED59.2 (A), LED60.2 (A), LED61.2 (A), LED62.2 (A), LED63.2 (A), LED64.2 (A), LED65.2 (A), LED66.2 (A), TH51.1, TH52.1, TH53.1, TH54.1, TH55.1, TH56.1, TH57.1, TH58.1, TH59.1, TH60.1, TH61.1, TH62.1, TH63.1, TH64.1, TH65.1, TH66.1
GNDPWR: C5.2, C7.1, C8.1, C9.1, J3.2, J4.2, Q51.3 (S), Q52.3 (S), Q53.3 (S), Q54.3 (S), Q55.3 (S), Q56.3 (S), Q57.3 (S), Q58.3 (S), Q59.3 (S), Q60.3 (S), Q61.3 (S), Q62.3 (S), Q63.3 (S), Q64.3 (S), Q65.3 (S), Q66.3 (S), R1.1, R5.2, RJ45-1.EH, U2.4 (GND)
GNDREF: C1.2, C3.1, D5.2 (A), D6.2 (A), D7.2 (A), D8.2 (A), J1.4, J2.4, R6.2, RN1.2 (R2.1), RN1.3 (R3.1), RN1.4 (R4.1), RN3.1 (R1.1), RN3.2 (R2.1), RN3.3 (R3.1), RN3.4 (R4.1), RN5.1 (R1.1), RN5.2 (R2.1), RN5.3 (R3.1), RN5.4 (R4.1), RN7.1 (R1.1), RN7.2 (R2.1), RN7.3 (R3.1), RN7.4 (R4.1), RN9.1 (R1.1), RN9.2 (R2.1), RN9.3 (R3.1), RN9.4 (R4.1), U1.10 (VSS), U3.2, U3.4, U3.6, U3.8, U4.2, U4.4, U4.6, U4.8, U5.2, U5.4, U5.6, U5.8, U6.2, U6.4, U6.6, U6.8
unnamed: C1.1, D1.2 (A), RN1.8 (R1.2), U1.18 (~RESET)
unnamed: D1.1 (K), SW1.5
unnamed: D2.1 (K), R1.2
unnamed: D3.1 (K), R5.1
unnamed: D4.1 (K), R6.1
unnamed: D67.2 (A), U3.15
unnamed: D68.2 (A), U3.13
unnamed: D69.2 (A), U3.11
unnamed: D70.2 (A), U3.9
unnamed: D71.2 (A), U4.9
unnamed: D72.2 (A), U4.11
unnamed: D73.2 (A), U4.13
unnamed: D74.2 (A), U4.15
unnamed: D75.2 (A), U5.9
unnamed: D76.2 (A), U5.11
unnamed: D77.2 (A), U5.13
unnamed: D78.2 (A), U5.15
unnamed: D79.2 (A), U6.9
unnamed: D80.2 (A), U6.11
unnamed: D81.2 (A), U6.13
unnamed: D82.2 (A), U6.15
unnamed: J1.3, J2.3
unnamed: LED51.1 (K), R51.2
unnamed: LED52.1 (K), R52.2
unnamed: LED53.1 (K), R53.2
unnamed: LED54.1 (K), R54.2
unnamed: LED55.1 (K), R55.2
unnamed: LED56.1 (K), R56.2
unnamed: LED57.1 (K), R57.2
unnamed: LED58.1 (K), R58.2
unnamed: LED59.1 (K), R59.2
unnamed: LED60.1 (K), R60.2
unnamed: LED61.1 (K), R61.2
unnamed: LED62.1 (K), R62.2
unnamed: LED63.1 (K), R63.2
unnamed: LED64.1 (K), R64.2
unnamed: LED65.1 (K), R65.2
unnamed: LED66.1 (K), R66.2
unnamed: R3.1, SW5.2
unnamed: R4.1, SW5.1
unnamed: RN1.7 (R2.2), SW1.6, U1.17 (A2)
unnamed: RN1.6 (R3.2), SW1.7, U1.16 (A1)
unnamed: RN1.5 (R4.2), SW1.8, U1.15 (A0)
unnamed: RN11.8 (R1.2), U1.1 (GPB0)
unnamed: RN11.7 (R2.2), U1.2 (GPB1)
unnamed: RN11.6 (R3.2), U1.3 (GPB2)
unnamed: RN11.5 (R4.2), U1.4 (GPB3)
unnamed: RN12.8 (R1.2), U1.25 (GPA4)
unnamed: RN12.7 (R2.2), U1.26 (GPA5)
unnamed: RN12.6 (R3.2), U1.27 (GPA6)
unnamed: RN12.5 (R4.2), U1.28 (GPA7)
unnamed: RN15.8 (R1.2), U1.5 (GPB4)
unnamed: RN15.7 (R2.2), U1.6 (GPB5)
unnamed: RN15.6 (R3.2), U1.7 (GPB6)
unnamed: RN15.5 (R4.2), U1.8 (GPB7)
unnamed: RN16.8 (R1.2), U1.21 (GPA0)
unnamed: RN16.7 (R2.2), U1.22 (GPA1)
unnamed: RN16.6 (R3.2), U1.23 (GPA2)
unnamed: RN16.5 (R4.2), U1.24 (GPA3)
unnamed: C6.2, U2.6 (BST)
unnamed: C6.1, L1.1, U2.5 (SW)
OptoIN: JP2.2 (C), U3.10, U3.12, U3.14, U3.16, U4.10, U4.12, U4.14, U4.16, U5.10, U5.12, U5.14, U5.16, U6.10, U6.12, U6.14, U6.16
RC1+: D51.1 (K), RJ45-1.A1, TH51.2
RC1-: D51.2 (A), Q51.1 (D), R51.1, RJ45-1.A2
RC2+: D52.1 (K), RJ45-1.A3, TH52.2
RC2-: D52.2 (A), Q52.1 (D), R52.1, RJ45-1.A6
RC3+: D53.1 (K), RJ45-1.A5, TH53.2
RC3-: D53.2 (A), Q53.1 (D), R53.1, RJ45-1.A4
RC4+: D54.1 (K), RJ45-1.A7, TH54.2
RC4-: D54.2 (A), Q54.1 (D), R54.1, RJ45-1.A8
RC5+: D55.1 (K), RJ45-1.B1, TH55.2
RC5-: D55.2 (A), Q55.1 (D), R55.1, RJ45-1.B2
RC6+: D56.1 (K), RJ45-1.B3, TH56.2
RC6-: D56.2 (A), Q56.1 (D), R56.1, RJ45-1.B6
RC7+: D57.1 (K), RJ45-1.B5, TH57.2
RC7-: D57.2 (A), Q57.1 (D), R57.1, RJ45-1.B4
RC8+: D58.1 (K), RJ45-1.B7, TH58.2
RC8-: D58.2 (A), Q58.1 (D), R58.1, RJ45-1.B8
RC9+: D59.1 (K), RJ45-1.C1, TH59.2
RC9-: D59.2 (A), Q59.1 (D), R59.1, RJ45-1.C2
RC10+: D60.1 (K), RJ45-1.C3, TH60.2
RC10-: D60.2 (A), Q60.1 (D), R60.1, RJ45-1.C6
RC11+: D61.1 (K), RJ45-1.C5, TH61.2
RC11-: D61.2 (A), Q61.1 (D), R61.1, RJ45-1.C4
RC12+: D62.1 (K), RJ45-1.C7, TH62.2
RC12-: D62.2 (A), Q62.1 (D), R62.1, RJ45-1.C8
RC13+: D63.1 (K), RJ45-1.D1, TH63.2
RC13-: D63.2 (A), Q63.1 (D), R63.1, RJ45-1.D2
RC14+: D64.1 (K), RJ45-1.D3, TH64.2
RC14-: D64.2 (A), Q64.1 (D), R64.1, RJ45-1.D6
RC15+: D65.1 (K), RJ45-1.D5, TH65.2
RC15-: D65.2 (A), Q65.1 (D), R65.1, RJ45-1.D4
RC16+: D66.1 (K), RJ45-1.D7, TH66.2
RC16-: D66.2 (A), Q66.1 (D), R66.1, RJ45-1.D8
RST: J1.6, J2.6, SW1.4
SCL: J1.1, J2.1, R3.2, U1.12 (SCK)
SDA: J1.2, J2.2, R4.2, U1.13 (SDA)
VCC: C3.2, D4.2 (A), J1.5, J2.5, RN1.1 (R1.1), SW1.1, SW1.2, SW1.3, SW5.3, SW5.4, U1.9 (VDD)
VDD: C5.1, D3.2 (A), J3.1, J4.1, JP1.3 (B), JP2.3 (B), JP3.1 (A)
p1-a: D8.1 (K), RN7.8 (R1.2), RN16.1 (R1.1), U3.7
p1-a5: D70.1 (K), Q51.2 (G)
p1-b: D8.3 (K), RN7.7 (R2.2), RN16.2 (R2.1), U3.5
p1-b5: D69.1 (K), Q52.2 (G)
p1-c: D8.4 (K), RN7.6 (R3.2), RN16.3 (R3.1), U3.3
p1-c5: D68.1 (K), Q53.2 (G)
p1-d: D8.5 (K), RN7.5 (R4.2), RN16.4 (R4.1), U3.1
p1-d5: D67.1 (K), Q54.2 (G)
p2-a: D5.1 (K), RN9.8 (R1.2), RN12.1 (R1.1), U4.7
p2-a5: D71.1 (K), Q55.2 (G)
p2-b: D5.3 (K), RN9.7 (R2.2), RN12.2 (R2.1), U4.5
p2-b5: D72.1 (K), Q56.2 (G)
p2-c: D5.4 (K), RN9.6 (R3.2), RN12.3 (R3.1), U4.3
p2-c5: D73.1 (K), Q57.2 (G)
p2-d: D5.5 (K), RN9.5 (R4.2), RN12.4 (R4.1), U4.1
p2-d5: D74.1 (K), Q58.2 (G)
p3-a: D6.1 (K), RN3.8 (R1.2), RN11.1 (R1.1), U5.7
p3-a5: D75.1 (K), Q59.2 (G)
p3-b: D6.3 (K), RN3.7 (R2.2), RN11.2 (R2.1), U5.5
p3-b5: D76.1 (K), Q60.2 (G)
p3-c: D6.4 (K), RN3.6 (R3.2), RN11.3 (R3.1), U5.3
p3-c5: D77.1 (K), Q61.2 (G)
p3-d: D6.5 (K), RN3.5 (R4.2), RN11.4 (R4.1), U5.1
p3-d5: D78.1 (K), Q62.2 (G)
p4-a: D7.1 (K), RN5.8 (R1.2), RN15.1 (R1.1), U6.7
p4-a5: D79.1 (K), Q63.2 (G)
p4-b: D7.3 (K), RN5.7 (R2.2), RN15.2 (R2.1), U6.5
p4-b5: D80.1 (K), Q64.2 (G)
p4-c: D7.4 (K), RN5.6 (R3.2), RN15.3 (R3.1), U6.3
p4-c5: D81.1 (K), Q65.2 (G)
p4-d: D7.5 (K), RN5.5 (R4.2), RN15.4 (R4.1), U6.1
p4-d5: D82.1 (K), Q66.2 (G)

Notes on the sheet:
Relay Coil 4+
Relay Coil 14 Out
Relay Coil 2+
Relay Driver Outputs
Relay Coil 13+
Relay Coil 1 Out
Relay Coil 7 Out
Relay Coil 10+
Relay Coil 16 Out
Relay Coil 15 Out
Relay Coil 12+
Relay Coil 12 Out
Relay Coil 7+
Relay Coil 13 Out
Relay Coil 1+
Relay Coil 3+
Relay Coil 15+
Relay Coil 14+
Relay Coil 8+
Relay Coil 11 Out
Relay Coil 4 Out
Relay Coil 3 Out
Relay Coil 6+
Relay Coil 6 Out
Relay Coil 2 Out
Relay Coil 5+
Relay Coil 5 Out
Relay Coil 9 Out
Relay Coil 10 Out
Relay Coil 16+
Relay Coil 9+
Relay Coil 11+
Relay Coil 8 Out

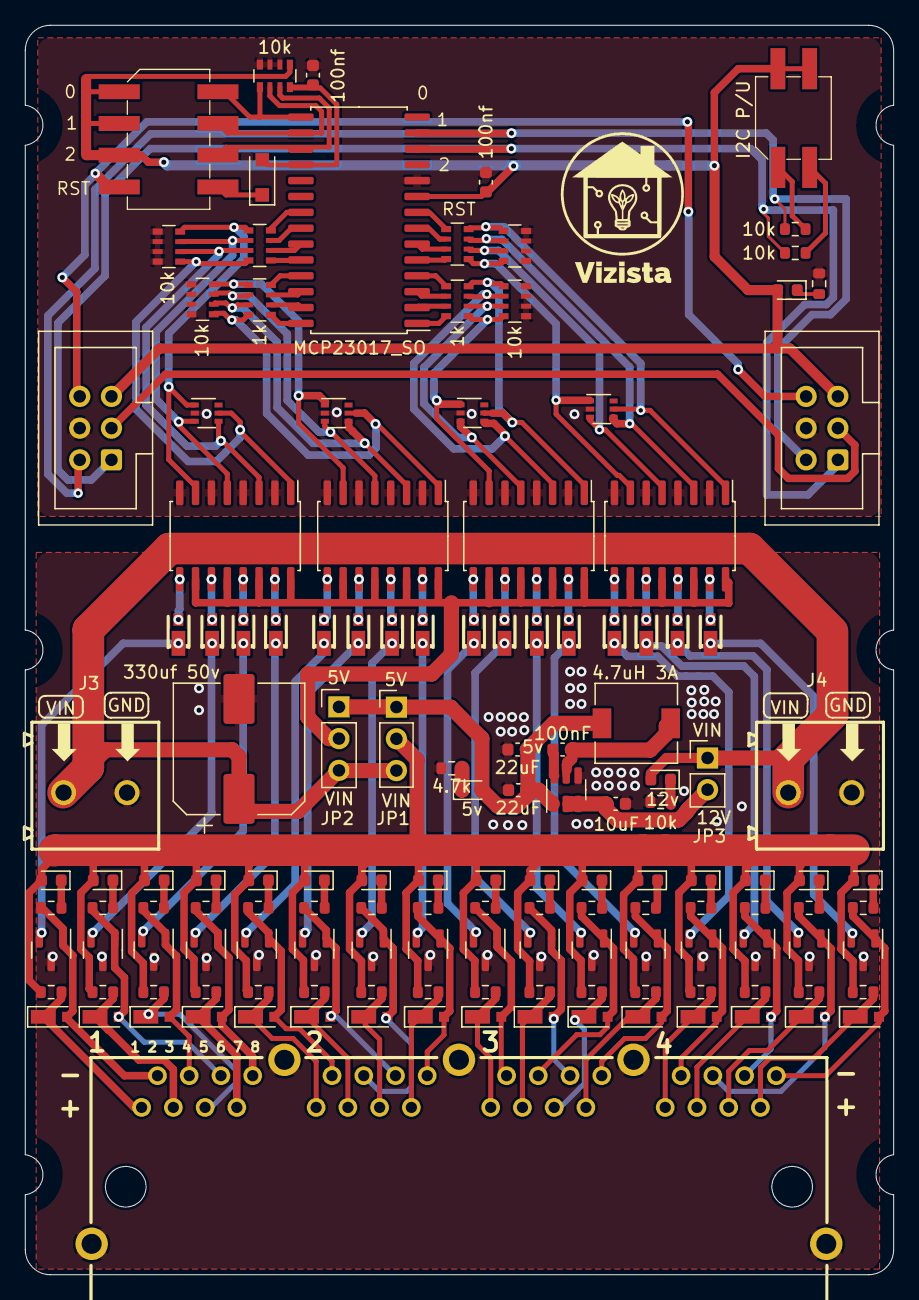
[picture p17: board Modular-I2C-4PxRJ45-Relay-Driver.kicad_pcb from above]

Board: 2 copper layers, 69.5 x 100.0 mm, 142 parts (0 on the bottom side), 136 nets.

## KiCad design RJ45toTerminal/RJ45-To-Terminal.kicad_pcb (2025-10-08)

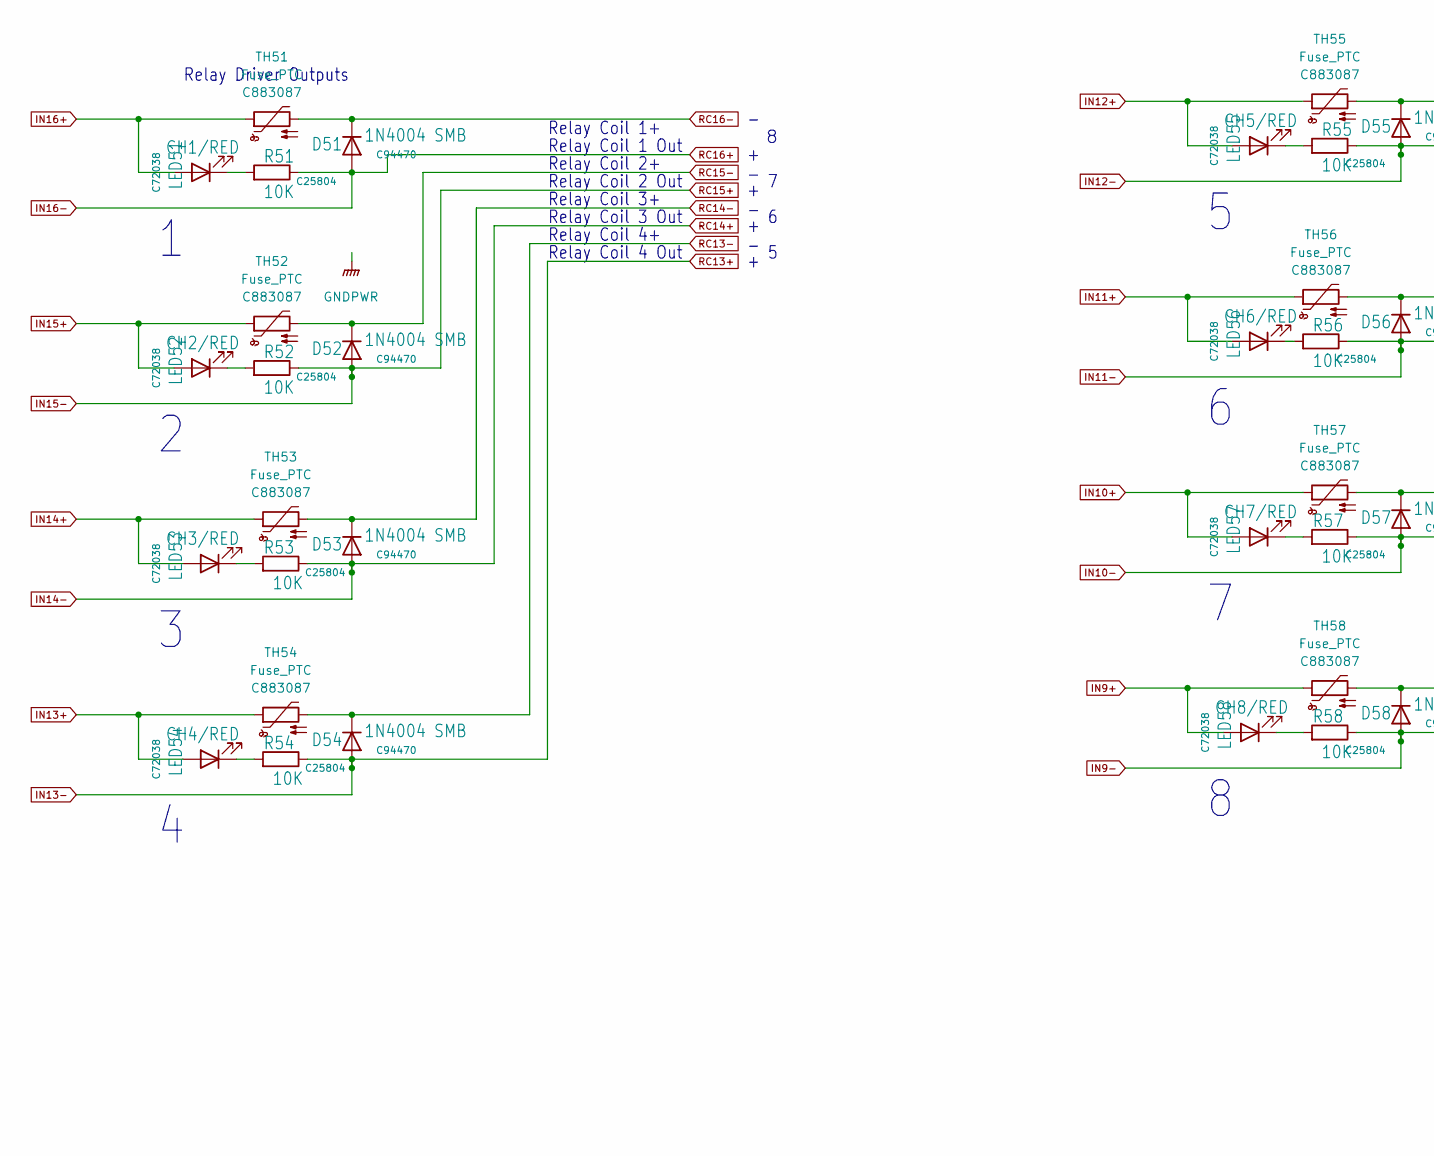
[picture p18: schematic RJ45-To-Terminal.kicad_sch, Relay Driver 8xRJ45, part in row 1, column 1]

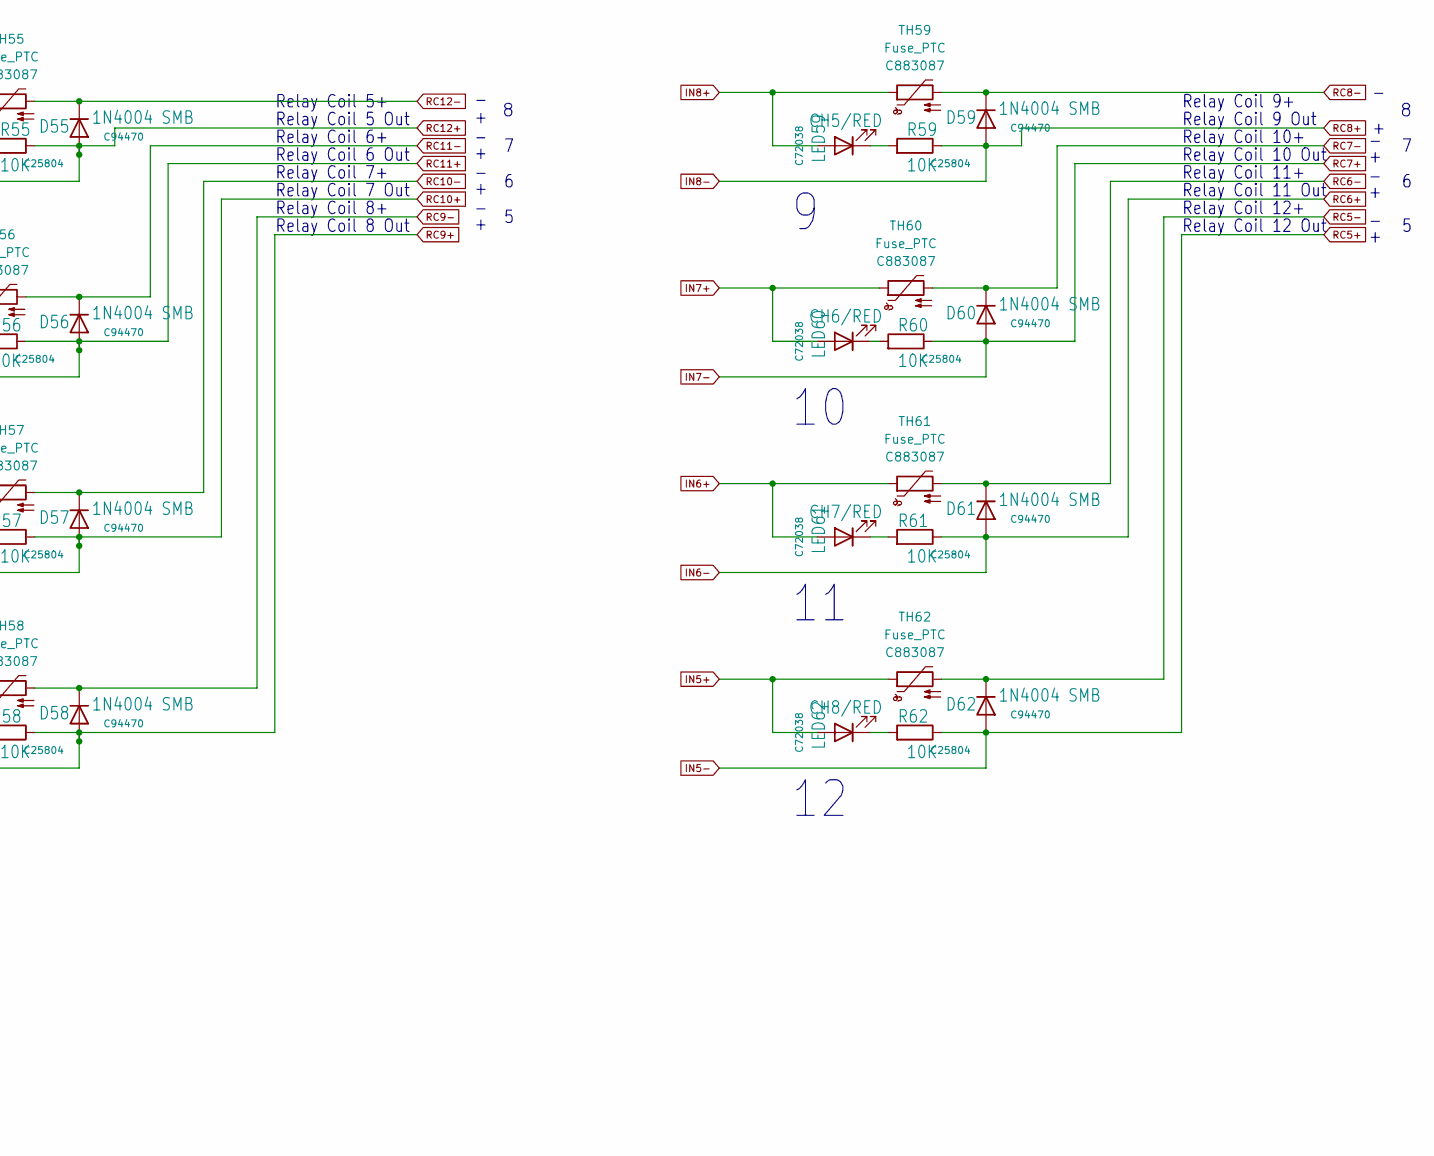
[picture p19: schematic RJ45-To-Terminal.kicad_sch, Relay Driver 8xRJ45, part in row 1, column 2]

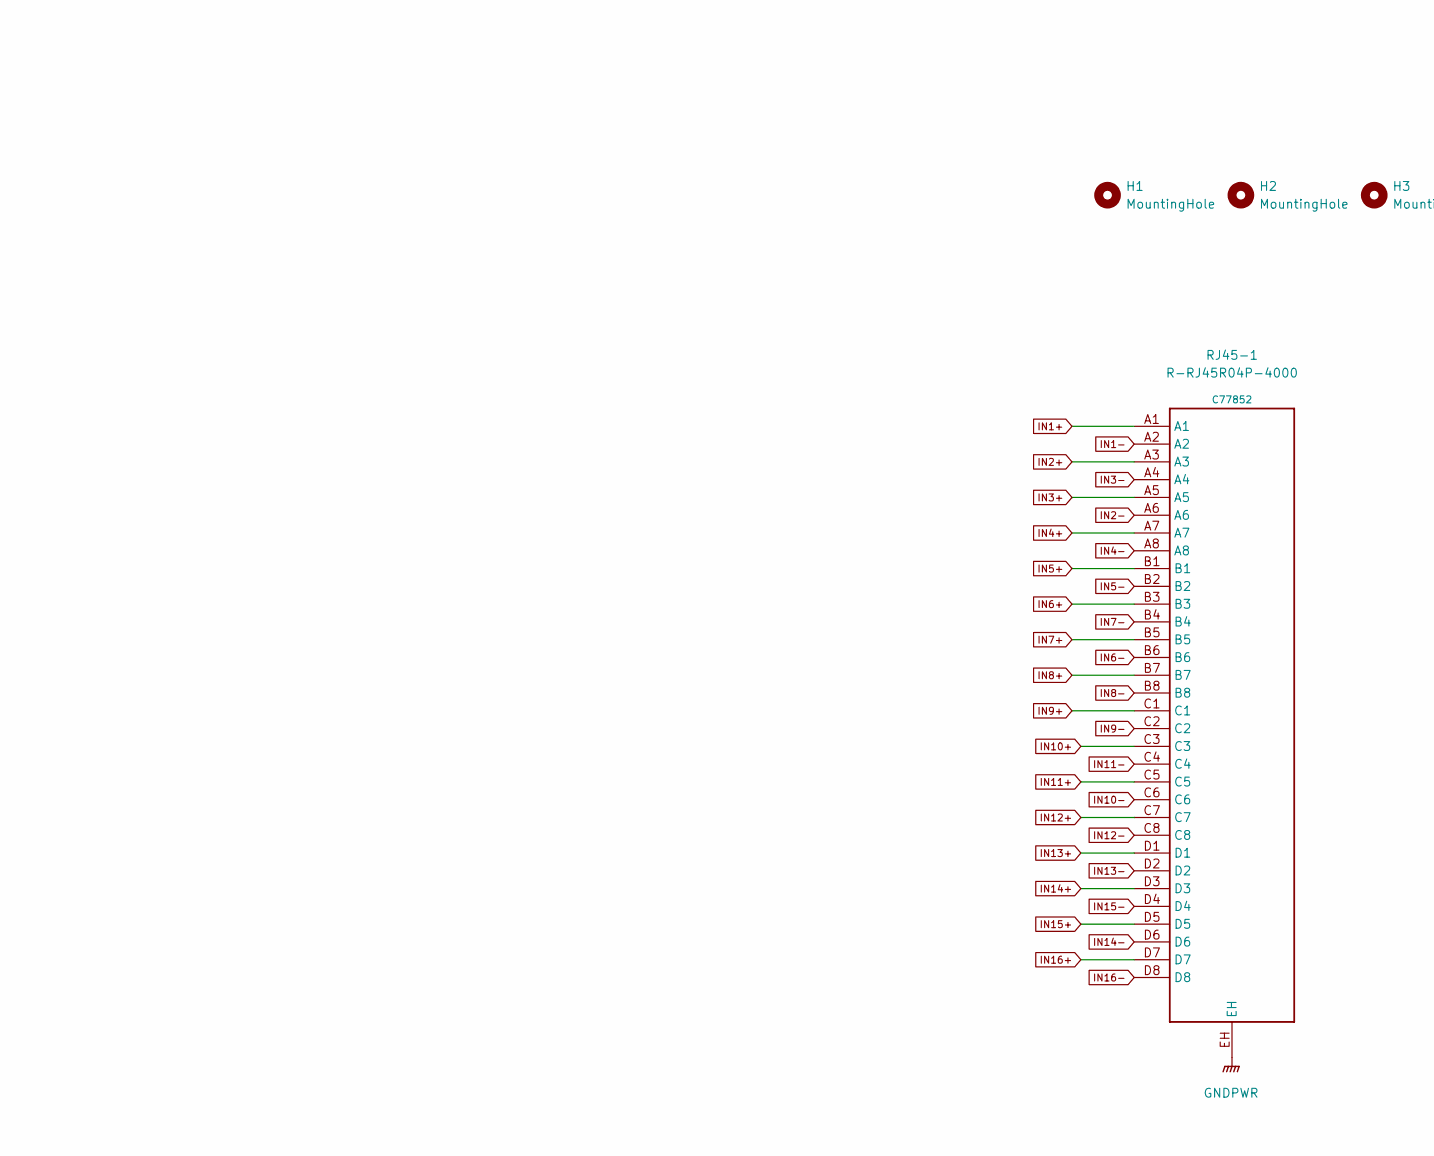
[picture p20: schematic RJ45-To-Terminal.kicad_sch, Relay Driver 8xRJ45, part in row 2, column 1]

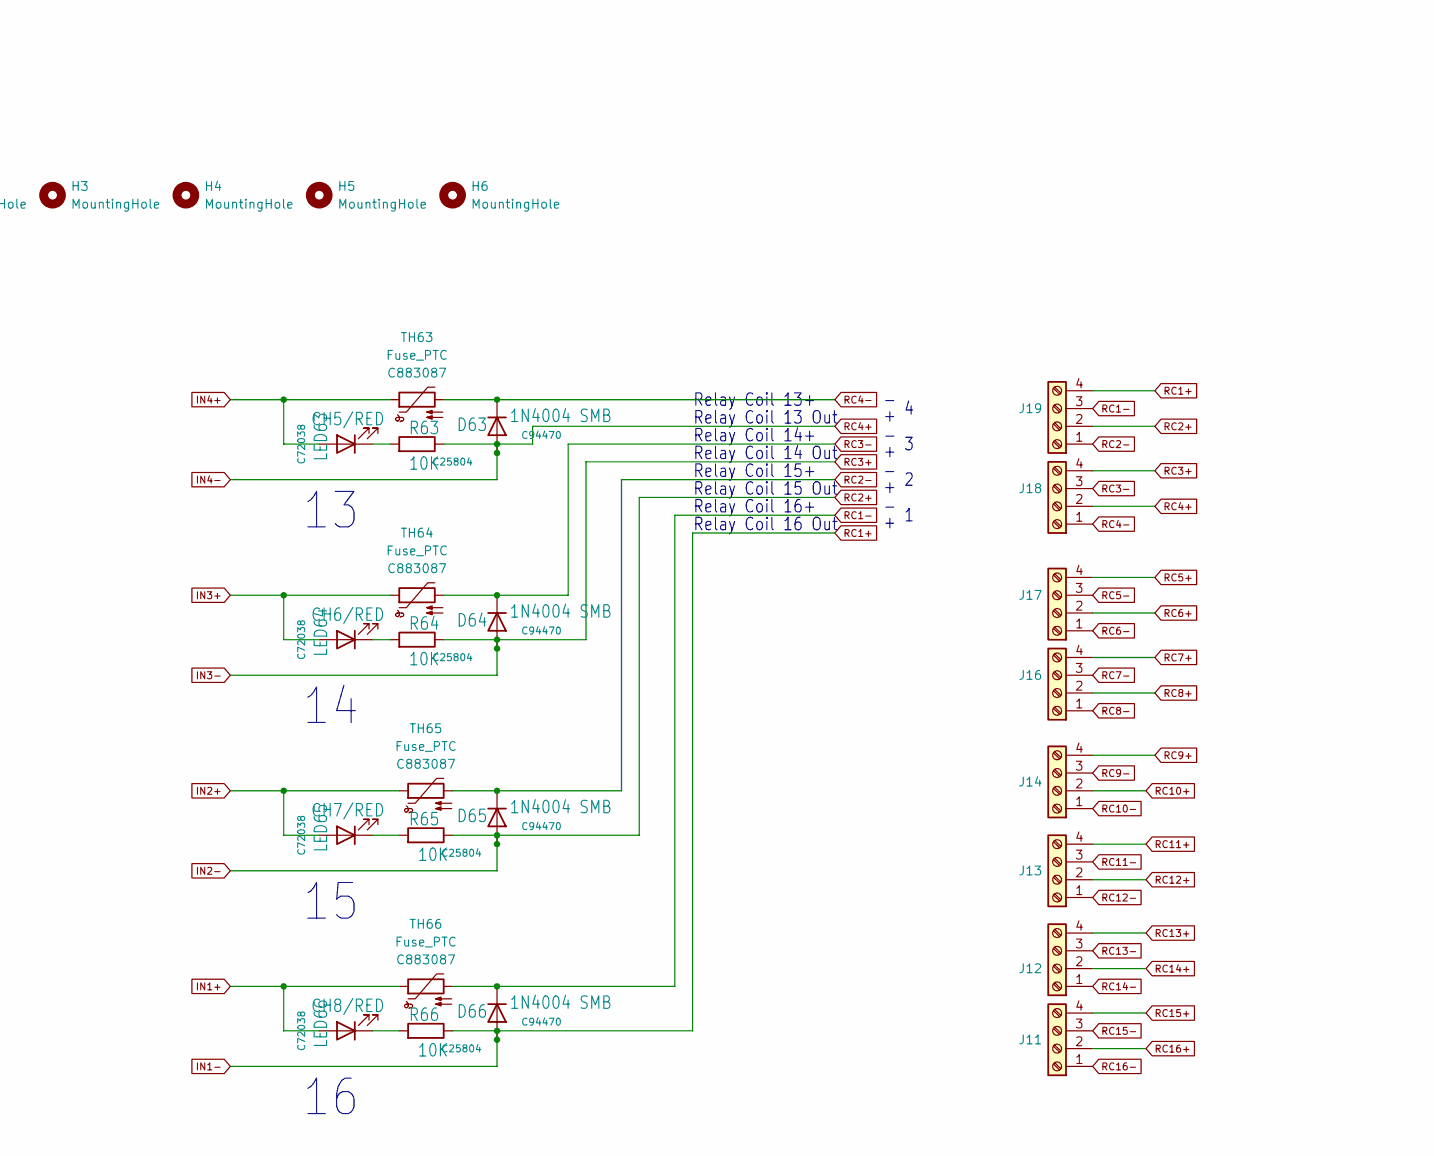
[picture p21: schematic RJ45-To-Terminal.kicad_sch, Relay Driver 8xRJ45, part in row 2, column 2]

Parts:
D51, D52, D53, D54, D55, D56, D57, D58, D59, D60, D61, D62, D63, D64, D65, D66: 1N4004 SMB; D_MicroSMP; LCSC C94470
H1, H2, H3, H4, H5, H6: MountingHole; MountingHole_3.2mm_M3
J11, J13, J16, J18: Screw_Terminal_01x04; CONN-TH_XY2500V-F-3.5-4P; LCSC C880556
J12, J14, J17, J19: Screw_Terminal_01x04; CONN-TH_XY2500R-G-3.5-4P; LCSC C880574
LED51: CH1/RED; LED_0603_1608Metric; LCSC1 C72038
LED52: CH2/RED; LED_0603_1608Metric; LCSC1 C72038
LED53: CH3/RED; LED_0603_1608Metric; LCSC1 C72038
LED54: CH4/RED; LED_0603_1608Metric; LCSC1 C72038
LED55, LED59, LED63: CH5/RED; LED_0603_1608Metric; LCSC1 C72038
LED56, LED60, LED64: CH6/RED; LED_0603_1608Metric; LCSC1 C72038
LED57, LED61, LED65: CH7/RED; LED_0603_1608Metric; LCSC1 C72038
LED58, LED62, LED66: CH8/RED; LED_0603_1608Metric; LCSC1 C72038
R51, R52, R53, R54, R55, R56, R57, R58, R59, R60, R61, R62, R63, R64, R65, R66: 10K; R_0603_1608Metric; LCSC C25804
RJ45-1: R-RJ45R04P-4000; CONN-TH_DS1129-02-S80BP; LCSC C77852
TH51, TH52, TH53, TH54, TH55, TH56, TH57, TH58, TH59, TH60, TH61, TH62, TH63, TH64, TH65, TH66: Fuse_PTC; R_0603_1608Metric; LCSC C883087

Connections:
GNDPWR: RJ45-1.EH
IN1+: LED66.2 (A), RJ45-1.A1, TH66.1
IN1-: D66.2 (A), J19.4, R66.1, RJ45-1.A2
IN2+: LED65.2 (A), RJ45-1.A3, TH65.1
IN2-: D65.2 (A), J19.2, R65.1, RJ45-1.A6
IN3+: LED64.2 (A), RJ45-1.A5, TH64.1
IN3-: D64.2 (A), J18.4, R64.1, RJ45-1.A4
IN4+: LED63.2 (A), RJ45-1.A7, TH63.1
IN4-: D63.2 (A), J18.2, R63.1, RJ45-1.A8
IN5+: LED62.2 (A), RJ45-1.B1, TH62.1
IN5-: D62.2 (A), J17.4, R62.1, RJ45-1.B2
IN6+: LED61.2 (A), RJ45-1.B3, TH61.1
IN6-: D61.2 (A), J17.2, R61.1, RJ45-1.B6
IN7+: LED60.2 (A), RJ45-1.B5, TH60.1
IN7-: D60.2 (A), J16.4, R60.1, RJ45-1.B4
IN8+: LED59.2 (A), RJ45-1.B7, TH59.1
IN8-: D59.2 (A), J16.2, R59.1, RJ45-1.B8
IN9+: LED58.2 (A), RJ45-1.C1, TH58.1
IN9-: D58.2 (A), J14.4, R58.1, RJ45-1.C2
IN10+: LED57.2 (A), RJ45-1.C3, TH57.1
IN10-: D57.2 (A), J14.2, R57.1, RJ45-1.C6
IN11+: LED56.2 (A), RJ45-1.C5, TH56.1
IN11-: D56.2 (A), J13.4, R56.1, RJ45-1.C4
IN12+: LED55.2 (A), RJ45-1.C7, TH55.1
IN12-: D55.2 (A), J13.2, R55.1, RJ45-1.C8
IN13+: LED54.2 (A), RJ45-1.D1, TH54.1
IN13-: D54.2 (A), J12.4, R54.1, RJ45-1.D2
IN14+: LED53.2 (A), RJ45-1.D3, TH53.1
IN14-: D53.2 (A), J12.2, R53.1, RJ45-1.D6
IN15+: LED52.2 (A), RJ45-1.D5, TH52.1
IN15-: D52.2 (A), J11.4, R52.1, RJ45-1.D4
IN16+: LED51.2 (A), RJ45-1.D7, TH51.1
IN16-: D51.2 (A), J11.2, R51.1, RJ45-1.D8
unnamed: LED51.1 (K), R51.2
unnamed: LED52.1 (K), R52.2
unnamed: LED53.1 (K), R53.2
unnamed: LED54.1 (K), R54.2
unnamed: LED55.1 (K), R55.2
unnamed: LED56.1 (K), R56.2
unnamed: LED57.1 (K), R57.2
unnamed: LED58.1 (K), R58.2
unnamed: LED59.1 (K), R59.2
unnamed: LED60.1 (K), R60.2
unnamed: LED61.1 (K), R61.2
unnamed: LED62.1 (K), R62.2
unnamed: LED63.1 (K), R63.2
unnamed: LED64.1 (K), R64.2
unnamed: LED65.1 (K), R65.2
unnamed: LED66.1 (K), R66.2
RC1-: D66.1 (K), J19.3, TH66.2
RC2-: D65.1 (K), J19.1, TH65.2
RC3-: D64.1 (K), J18.3, TH64.2
RC4-: D63.1 (K), J18.1, TH63.2
RC5-: D62.1 (K), J17.3, TH62.2
RC6-: D61.1 (K), J17.1, TH61.2
RC7-: D60.1 (K), J16.3, TH60.2
RC8-: D59.1 (K), J16.1, TH59.2
RC9-: D58.1 (K), J14.3, TH58.2
RC10-: D57.1 (K), J14.1, TH57.2
RC11-: D56.1 (K), J13.3, TH56.2
RC12-: D55.1 (K), J13.1, TH55.2
RC13-: D54.1 (K), J12.3, TH54.2
RC14-: D53.1 (K), J12.1, TH53.2
RC15-: D52.1 (K), J11.3, TH52.2
RC16-: D51.1 (K), J11.1, TH51.2

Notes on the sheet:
Relay Coil 4+
Relay Coil 14 Out
Relay Coil 2+
Relay Driver Outputs
Relay Coil 13+
Relay Coil 1 Out
Relay Coil 7 Out
Relay Coil 10+
Relay Coil 16 Out
Relay Coil 15 Out
Relay Coil 12+
Relay Coil 12 Out
Relay Coil 7+
Relay Coil 13 Out
Relay Coil 1+
Relay Coil 3+
Relay Coil 15+
Relay Coil 14+
Relay Coil 8+
Relay Coil 11 Out
Relay Coil 4 Out
Relay Coil 3 Out
Relay Coil 6+
Relay Coil 6 Out
Relay Coil 2 Out
Relay Coil 5+
Relay Coil 5 Out
Relay Coil 9 Out
Relay Coil 10 Out
Relay Coil 16+
Relay Coil 9+
Relay Coil 11+
Relay Coil 8 Out

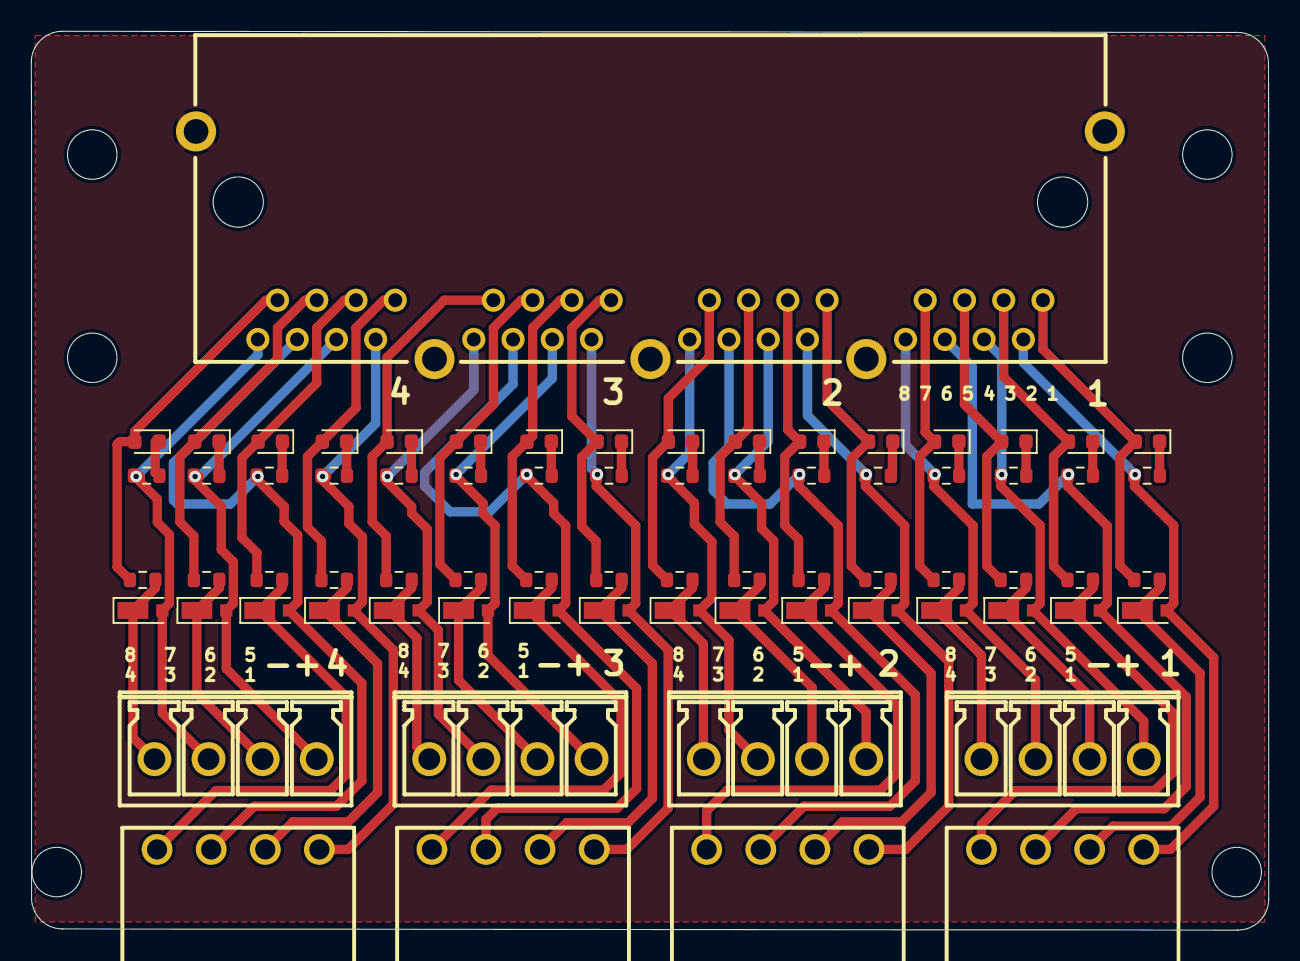
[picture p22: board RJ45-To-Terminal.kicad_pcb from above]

Board: 2 copper layers, 80.1 x 58.2 mm, 79 parts (0 on the bottom side), 64 nets.

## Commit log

2023-11-01 added release files
    [Modular-I2C-4PxRJ45-Relay-Driver-B_Cu.gbr, Modular-I2C-4PxRJ45-Relay-Driver-B_Mask.gbr, Modular-I2C-4PxRJ45-Relay-Driver-B_Paste.gbr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]
2023-11-01 added 3d model
    [Modular-I2C-4PxRJ45-Relay-Driver.kicad_pcb, Modular-I2C-4PxRJ45-Relay-Driver.kicad_sch]
2023-11-04 optocoupler update
    [Modular-I2C-4PxRJ45-Relay-Driver.kicad_pcb, Modular-I2C-4PxRJ45-Relay-Driver.kicad_sch]
2023-11-05 added 3d models
    [Modular-I2C-4PxRJ45-Relay-Driver.kicad_pcb, Modular-I2C-4PxRJ45-Relay-Driver.kicad_sch]
2023-11-06 3d update, manufacturing files
    [Modular-I2C-4PxRJ45-Relay-Driver-CuBottom.gbr, Modular-I2C-4PxRJ45-Relay-Driver-CuTop.gbr, Modular-I2C-4PxRJ45-Relay-Driver-EdgeCuts.gbr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]
2023-11-08 clean up
    [Modular-I2C-4PxRJ45-Relay-Driver.kicad_pcb]
2023-11-09 production files
    [Modular-I2C-4PxRJ45-Relay-Driver-B_Cu.gbl, Modular-I2C-4PxRJ45-Relay-Driver-B_Mask.gbs, Modular-I2C-4PxRJ45-Relay-Driver-B_Paste.gbp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]
2023-11-09 images and fabrication files
    [Modular-I2C-4PxRJ45-Relay-Driver-B_Cu.gbr, Modular-I2C-4PxRJ45-Relay-Driver-B_Mask.gbr, Modular-I2C-4PxRJ45-Relay-Driver-B_Silks.gbr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]
2023-11-10 RJ45 to Pluggable break out
    [Modular-I2C-4PxRJ45-Relay-Driver-B_Cu.gbl, Modular-I2C-4PxRJ45-Relay-Driver-B_Cu.gbr, Modular-I2C-4PxRJ45-Relay-Driver-B_Mask.gbr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]
2023-11-10 read me update and label
    [Modular-I2C-4PxRJ45-Relay-Driver.kicad_pcb, RJ45-To-Terminal.kicad_pcb]
2023-11-10 folder cleanup
    [Modular-I2C-4PxRJ45-Relay-Driver-B_Cu.gbl, Modular-I2C-4PxRJ45-Relay-Driver-B_Mask.gbs, Modular-I2C-4PxRJ45-Relay-Driver-B_Paste.gbp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]
2025-04-09 updated RJ45ToTerminal with additional space between pluggable conenctor
    [Modular-I2C-4PxRJ45-Relay-Driver-CuBottom.gbr, Modular-I2C-4PxRJ45-Relay-Driver-CuTop.gbr, Modular-I2C-4PxRJ45-Relay-Driver-EdgeCuts.gbr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]
2025-07-28 updated to support 5V output for fan speed control in rev2
    [Modular-I2C-4PxRJ45-Relay-Driver-B_Cu.gbl, Modular-I2C-4PxRJ45-Relay-Driver-B_Cu.gbr, Modular-I2C-4PxRJ45-Relay-Driver-B_Mask.gbr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]
2025-10-06 5V input suport
    [Modular-I2C-4PxRJ45-Relay-Driver.kicad_pcb, Modular-I2C-4PxRJ45-Relay-Driver.kicad_sch, RJ45-To-Terminal.kicad_pcb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]
2025-10-08 Fixed foot print and lcsc part id
    [Modular-I2C-4PxRJ45-Relay-Driver.kicad_pcb, Modular-I2C-4PxRJ45-Relay-Driver.kicad_sch, RJ45-To-Terminal.kicad_pcb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]
